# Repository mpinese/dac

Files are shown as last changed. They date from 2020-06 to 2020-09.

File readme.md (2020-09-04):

# Note

This project is still under active design, and is not yet completed! Do not build it expecting a functional device... yet.

# An (Almost) No Compromise USB Stereo DAC

This project describes the hardware and firmware for a high-quality DIY USB stereo digital to analogue converter (DAC) with optional integrated digital volume control and headphone amplifier.

## Background

I was after a DAC for my computer headphone setup. Seeing as I enjoy a bit of DIY hardware, I thought to have a go at designing the ideal DAC for me. This would be a high-quality but fairly compact single-box DAC, with integrated preamp and headphone amplifier. If stereo line out and digital (eg S/PDIF in) could be included with minimal effort that would be a bonus.

## Design philosophy

The design is balanced towards maximum audio quality while hopefully avoiding audiophile silliness. Close attention is paid to performance of the key components, gain structure, power rails, stability, and transfer characteristics in the 20-20kHz spectrum. However, you won't see esoteric components, valves, absurdly overspecified linear power supplies / space heaters, etc.

Key principles in the design were:
1. Use asynchronous mode USB audio. I want the PC to have as little influence as possible on the audio playback.
2. Keep the signal digital for as long as possible. For example, perform volume control digitally, rather than using an analogue attenuation stage, which can introduce issues with rolloff and noise.
3. Maintain a simple and clean analog signal path, ideally DC-coupled.
4. Have a solid justification for each design decision; try and avoid reflexive overkill approaches.
5. Where suitable, source components from the [JLCPCB SMT parts library](https://jlcpcb.com/parts/componentSearch). This is a practical and cost-saving measure that is well-worth it for non-critical things like pull-up resistors and decoupling caps.
6. Keep cost under control. Only use high-cost components if lower-cost alternatives are unsuitable.

I would have liked to add '0. Test everything, remove anything unnecessary' but unfortuantely I do not have the kind of test equipment needed to really challenge the design. Therefore some design choices, for example the supply decoupling or separate PSU enclosure, feel a bit over-the-top and can probably be optimised.

## Architecture

```
                                     Panel controls
                                           |
                                           v
                                     +--- MCU ---+
                                     |           |
                                     v           v
  Computer  -->  USB to I2S  -->  Receiver -->  DAC  -->  I2V  -->  Amplifier  -->  Headphones
                                  and ASRC                 |
                                     ^                     v
                                     |                  Line out
                                 Digital in            (3.472 Vpp)
```

* USB to I2S: [Amanero module](https://amanero.com/). A well-established solution for asynchronous USB to I2S conversion. I considered adopting a DIY approach for this stage, but there's no way I could replicate the Amanero's functionality without an investment of effort that far exceeds the cost of the module.
* Clock: Onboard 24.576 MHz oscillator driving both the ASRC and the DAC. The Amanero MCLK output is not used. Simulations indicated that the Kyocera ### is good enough here, and that the popular Crystek CHD series crystal, which has better specs but costs 10X more, is overkill.
* Receiver and ASRC: SRC4392, converting input to fs=96 kHz. This stage also performs digital volume control / attenuation if required.
* DAC: PCM1792A running at fs=96 kHz, with slow rolloff reconstruction filter.
* I2V: Op-amp based, standard Philips architecture of dual transimpedance amplifiers followed by a difference stage. OPA1612 devices for minimum noise. Gain flat within 0.1 dB 20 Hz to 20 kHz. Phase linear within 5 deg to 20 kHz (group delay < 0.1 ms). Total noise < 700 nV RMS (20 Hz - 20 kHz), equivalent to -125 dB relative to +4 dBu output level.
* Amplifier: OPA1612 + LME49600 buffer in feedback loop, unity gain (therefore maximum output level is 3.472 Vpp, matching the line out). AC-coupled input to avoid headphone damage in the case of DC signal, -3 dB at 7.7 Hz, -0.6 dB at 20 Hz, -0.1 dB at 50 Hz and higher; group delay 2.6 ms at 20 Hz, < 0.5 ms at 50 Hz and higher.  Somewhat overkill: characterised down to 16 ohm headphones, stable for all reasonable capacitances, and should be capable of driving any dynamic headphone or IEM out there.
* MCU: STM8S003F3P
* PSU: Switchmode modules for analog and digital supplies, in an external enclosure with LC filtering. In the main DAC enclosure, TPS7A linear postregulators for analog rails.

## Capabilities

* USB input: 
* Digital input: 
* Headphone output: 

## Options

The design is modular and modules can be left out to cut costs or change functionality.  The main modules are:

### Core DAC: essential

This is the only required module.  It performs USB --> stereo analog conversion.

#### Line out startup mute: optional

This module mutes the stereo output while the power rails are unstable (eg during startup).  It prevents the "thump" noise that can often happen when switching the DAC on or off.  However this may not be required in some configurations.

To disable this module, leave out components: 

### Volume control: optional (though highly recommended if headphones are used)

To disable this module, bridge ###

### Headphone amplifier: optional

Components: 

#### Headphone startup mute: optional

Components: 

## Licence

Hardware designs (schematics, PCB layouts, and enclosure plans), software, and documentation are licensed for reuse under the Creative Commons Attribution 4.0 Licence (CC BY 4.0). For more details on this licence, visit https://creativecommons.org/licenses/by/4.0/.

Component models (3D and 2D) under the design/pcbs/lib directory, and simulation models (`*.s*p`, `*.lib`, `*.tld`, `*.TSM` under the simulations directory) remain the property of their creators and are not covered by this CC BY 4.0 licence.

The Kicad BOM template bom2grouped_csv_jlcpcb.xsl was created bt arturo182, see https://gist.github.com/arturo182/a8c4a4b96907cfccf616a1edb59d0389.

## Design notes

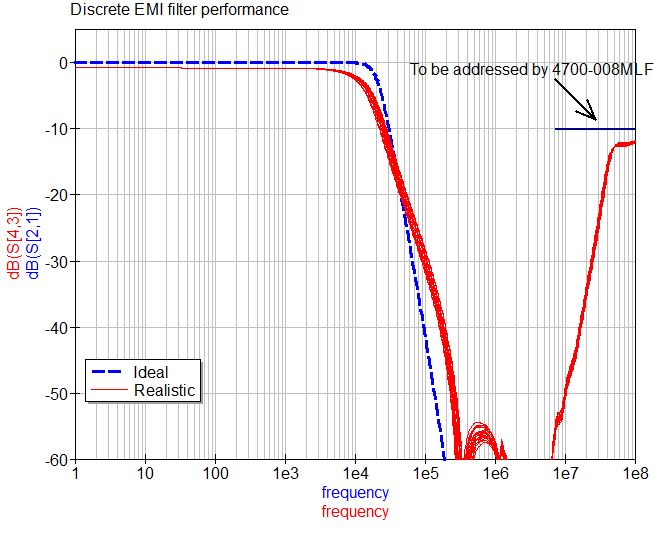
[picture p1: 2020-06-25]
simulations/qucsstudio/emi_filter.png

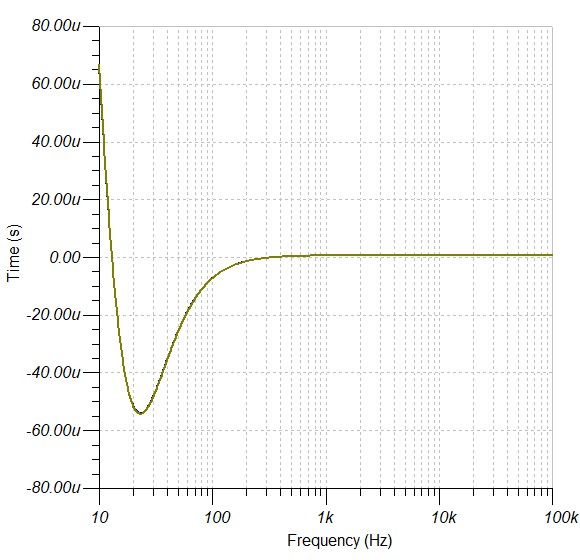
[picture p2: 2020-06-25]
simulations/tina-ti/i2v_delay.jpg

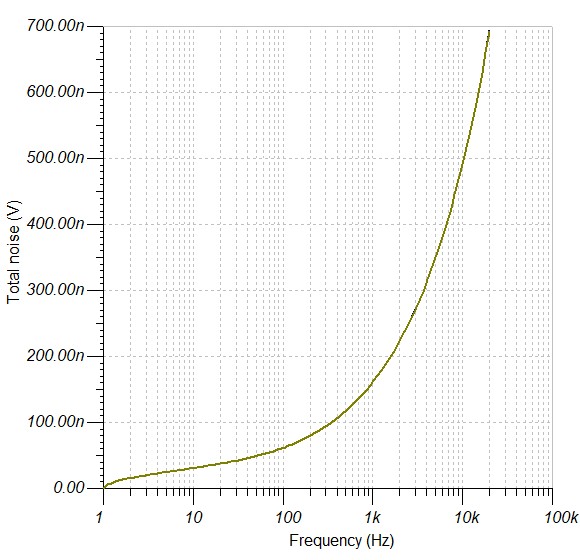
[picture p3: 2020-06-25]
simulations/tina-ti/i2v_noise.jpg

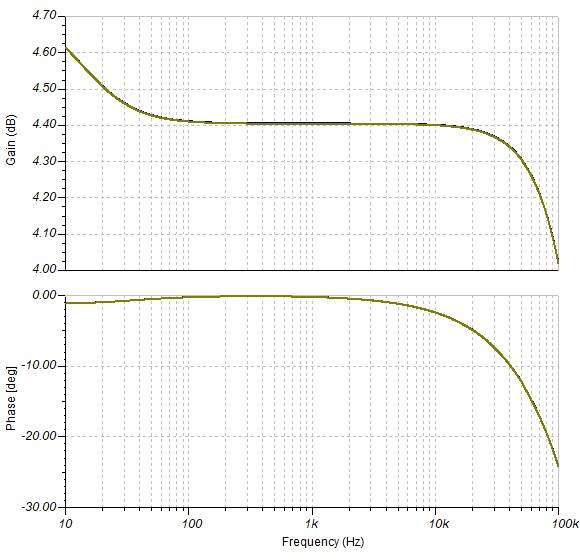
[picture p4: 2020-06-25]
simulations/tina-ti/I2V_ac.jpg

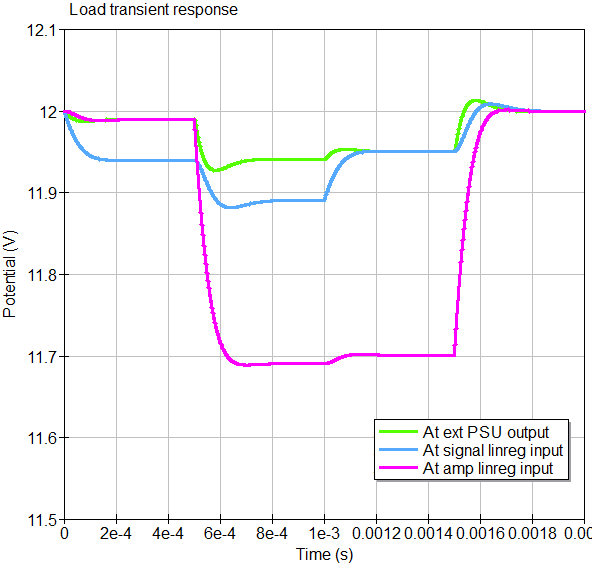
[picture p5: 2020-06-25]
simulations/qucsstudio/psu_transient.png

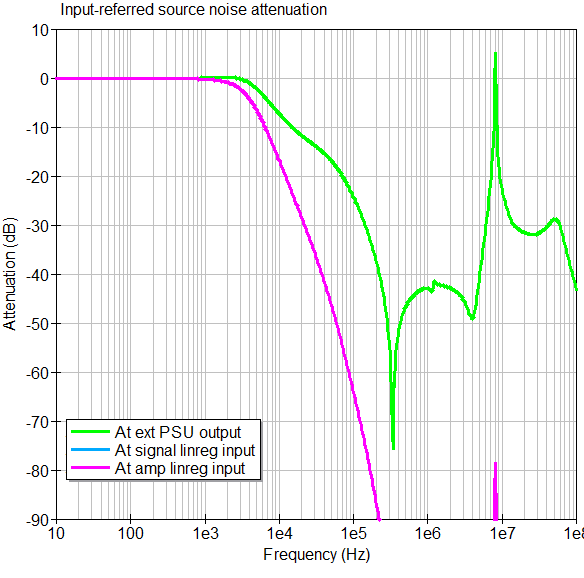
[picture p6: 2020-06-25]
simulations/qucsstudio/psu_ac.png

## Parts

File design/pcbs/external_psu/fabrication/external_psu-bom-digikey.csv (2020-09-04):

Comment | Designator | Footprint | DigiKey | Quantity
6.8u | C1,C13,C2,C14,C3,C15 | Capacitor_THT:CP_Radial_D5.0mm_P2.00mm | 565-4006-ND | 6
2.2u | C4,C10,C5,C11,C6,C12 | Capacitor_SMD:C_1206_3216Metric | 1276-3137-1-ND | 6
15n | C7,C8,C9 | Capacitor_SMD:C_0805_2012Metric_Pad1.15x1.40mm_HandSolder | 732-12189-1-ND | 3
~ | #FB1 |  | 240-2497-ND | 1
EMI_Filter_CLC | FL1,FL2,FL3 | dac:4700-008MLF | 410-1196-1-ND | 3
15u | L1,L2,L3 | dac:NRS5020T150MMGJ | 587-2410-1-ND | 3
RAC20-12DK | PS1 | CONV_RAC20-12DK | 945-3239-ND | 1
RAC03-05SK | PS2 | CONV_RAC03-05SK | 945-3441-ND | 1
IEC 320-C14 socket | #J1 |  | Q334-ND | 1
XLR5 | #J2 |  | 1937-1035-ND | 1

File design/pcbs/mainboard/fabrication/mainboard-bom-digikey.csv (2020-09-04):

Comment | Designator | Footprint | DigiKey | Quantity
KC3225K24.5760C1GE00 | U6 | Crystal:Crystal_SMD_3225-4Pin_3.2x2.5mm | 1253-1407-1-ND | 1
100u | C16 | Capacitor_THT:CP_Radial_D8.0mm_P3.50mm | 1572-1662-ND | 1
TPS79318-EP | U10 | Package_TO_SOT_SMD:SOT-23-5 | 296-12155-1-ND | 1
SRC4392 | U11 | Package_QFP:TQFP-48_7x7mm_P0.5mm | 296-19740-1-ND | 1
PCM1792A | U12 | Package_SO:SSOP-28_5.3x10.2mm_P0.65mm | 296-26303-5-ND | 1
TPS7A30 | U3,U16 | Package_SO:MSOP-8-1EP_3x3mm_P0.65mm_EP1.68x1.88mm_ThermalVias | 296-27750-1-ND | 2
TPS7A49 | U2,U19,U5 | Package_SO:MSOP-8-1EP_3x3mm_P0.65mm_EP1.68x1.88mm_ThermalVias | 296-27751-1-ND | 3
TLV1117-33 | U4 | Package_TO_SOT_SMD:SOT-223-3_TabPin2 | 296-28778-1-ND | 1
OPA1612AxD | U18,U15,U9,U13 | Package_SO:SOIC-8_3.9x4.9mm_P1.27mm | 296-39098-1-ND | 4
LME49600 | U17,U20 | Package_TO_SOT_SMD:TO-263-5_TabPin3 | 296-43968-5-ND | 2
Si8645BA-B-IU | U14 | Package_SO:QSOP-16_3.9x4.9mm_P0.635mm | 336-2096-5-ND | 1
EC2-12NU | K3,K4 | RELAY_EC2-5NU | 399-11029-5-ND | 2
EC2-5NU | K1,K2 | mainboard:RELAY_EC2-5NU | 399-11052-5-ND | 2
1.2n | C37,C38,C65,C66 | Capacitor_SMD:C_0603_1608Metric | 399-14950-1-ND | 4
430p | C47,C24,C69,C53 | Capacitor_SMD:C_0603_1608Metric | 399-15401-1-ND | 4
4.7 | R49 | Resistor_SMD:R_0603_1608Metric | 408-1436-1-ND | 1
2.2u | C80,C79,C94,C95 | Capacitor_THT:C_Rect_L18.0mm_W11.0mm_P15.00mm_FKS3_FKP3 | 732-11840-ND | 4
47u | C15,C12,C4,C5,C93,C78,C86,C77,C6 | Capacitor_THT:CP_Radial_D8.0mm_P3.50mm | 732-6324-1-ND | 9
47u | C42,C59,C29 | Capacitor_THT:CP_Radial_D5.0mm_P2.00mm | 732-9306-1-ND | 3
25 | R38,R42 | Resistor_SMD:R_0603_1608Metric | 764-1409-1-ND | 2
5PB1102 | U8 | Package_SO:TSSOP-8_4.4x3mm_P0.65mm | 800-2889-5-ND | 1
AudioJackSw | J10 | mainboard:Amphenol_ACJS-MHOM | 889-1818-ND | 1
P091S-FC20BR10K | RV1 | mainboard:P091S-FC20BR10K | 987-1283-ND | 1
1k | R30,R28,R50,R48 | Resistor_SMD:R_0603_1608Metric | RG16N1.0KWCT-ND | 4
270 | R33,R34,R46,R47 | Resistor_SMD:R_0603_1608Metric | RG16N270WCT-ND | 4
820 | R35,R27,R53,R43 | Resistor_SMD:R_0603_1608Metric | RG16N820WCT-ND | 4
4.7k | R60,R70 | Resistor_SMD:R_0603_1608Metric | RG16P4.7KBCT-ND | 2
Conn_Coaxial | J7,J8 | Connector_Wire:SolderWirePad_1x02_P5.08mm_Drill1.5mm | SC1828-ND | 2
XLR5 | #J3 |  | IO-XLR5-M-EV | 1

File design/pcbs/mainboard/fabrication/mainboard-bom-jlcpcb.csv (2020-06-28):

Comment | Designator | Footprint | LCSC
10n | C18,C17,C9,C11,C72,C87,C85,C71,C28,C19,C21,C34,C22,C35 | Capacitor_SMD:C_0603_1608Metric | C14663
0.1u | C44,C61,C54,C51,C33,C60,C45,C84,C88,C81,C96,C75,C92,C32,C63,C48,C68,C58,C26,C41,C46,C57,C3,C2 | Capacitor_SMD:C_0603_1608Metric | C14663
10n | C39 | Capacitor_SMD:C_0402_1005Metric | C15195
1 | R2,R3,R4,R62,R56 | Resistor_SMD:R_1206_3216Metric | C17928
75 | R16 | Resistor_SMD:R_1206_3216Metric | C17985
SS8050 | Q12,Q11,Q9,Q8,Q1,Q2,Q4,Q5,Q6,Q7 | Package_TO_SOT_SMD:SOT-23 | C2150
2.2u | C55 | Capacitor_SMD:C_0603_1608Metric | C23630
100 | R8,R7 | Resistor_SMD:R_0402_1005Metric | C25076
50 | R39,R41,R44 | Resistor_SMD:R_0402_1005Metric | C25082
10k | R32,R37,R1,R5,R71,R21 | Resistor_SMD:R_0402_1005Metric | C25744
120k | R23,R22,R55,R65 | Resistor_SMD:R_0402_1005Metric | C25750
15k | R73,R20 | Resistor_SMD:R_0402_1005Metric | C25756
220k | R26 | Resistor_SMD:R_0402_1005Metric | C25767
22k | R63,R31 | Resistor_SMD:R_0402_1005Metric | C25768
27k | R24,R10,R58,R67 | Resistor_SMD:R_0402_1005Metric | C25771
330k | R18,R17,R54,R64 | Resistor_SMD:R_0402_1005Metric | C25778
33k | R19,R15,R57,R66 | Resistor_SMD:R_0402_1005Metric | C25779
2.2k | R74,R72,R11,R13 | Resistor_SMD:R_0402_1005Metric | C25879
2.4k | R9,R6 | Resistor_SMD:R_0402_1005Metric | C25882
5.6k | R69,R68,R12,R14 | Resistor_SMD:R_0402_1005Metric | C25908
1u | C7,C10,C8,C73,C89,C20,C1 | Capacitor_SMD:C_0805_2012Metric | C28323
68k | R25 | Resistor_SMD:R_0402_1005Metric | C36871
22u | C40,C82 | Capacitor_SMD:C_0805_2012Metric | C45783
2.2u | C14,C13,C76,C90,C27 | Capacitor_SMD:C_1206_3216Metric | C50254
STM8S003F3P | U1 | Package_SO:TSSOP-20_4.4x6.5mm_P0.65mm | C52717
M7 | D1 | Diode_SMD:D_SOD-123F | C64898
D | D5,D4 | Diode_SMD:D_SOD-123F | C64898
10u | C43,C30,C64,C83,C97,C74,C91,C67,C56,C49,C31,C25,C52,C70,C23,C50,C36,C62 | Capacitor_Tantalum_SMD:CP_EIA-3216-18_Kemet-A | C7171
5V6 | D7,D6,D2,D3 | Diode_SMD:D_MiniMELF | C8062
SS8550 | Q10,Q3 | Package_TO_SOT_SMD:SOT-23 | C8542

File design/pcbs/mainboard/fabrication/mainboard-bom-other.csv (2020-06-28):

Comment | Designator | Footprint
Optional | FB1,FB2 | Resistor_SMD:R_0603_1608Metric_Pad1.05x0.95mm_HandSolder
MountingHole | H2,H4,H1,H5,H3 | MountingHole:MountingHole_3.2mm_M3_Pad_Via
Conn_01x01 | J2,J1,J3,J4 | Connector_Wire:SolderWirePad_1x01_Drill1.5mm
Conn_01x04 | J6,J5 | Connector_PinHeader_2.54mm:PinHeader_1x04_P2.54mm_Vertical
Conn_01x03 | J9 | Connector_PinHeader_2.54mm:PinHeader_1x03_P2.54mm_Vertical
Jumper_NC_Small | JP1 | Jumper:SolderJumper-2_P1.3mm_Bridged2Bar_Pad1.0x1.5mm
Jumper | JP10 | Jumper:SolderJumper-2_P1.3mm_Bridged2Bar_Pad1.0x1.5mm
Jumper | JP2,JP3 | Connector_PinHeader_2.54mm:PinHeader_1x02_P2.54mm_Vertical
~ | JP4,JP5,JP9,JP8,JP7,JP6 | Connector_PinHeader_2.54mm:PinHeader_1x02_P2.54mm_Vertical
Optional | R29,R36,R52,R51,R45,R40 | Resistor_THT:R_Axial_DIN0204_L3.6mm_D1.6mm_P5.08mm_Horizontal
Open | R59,R76 | Resistor_THT:R_Axial_DIN0207_L6.3mm_D2.5mm_P10.16mm_Horizontal
0 | R61,R75 | Resistor_THT:R_Axial_DIN0207_L6.3mm_D2.5mm_P10.16mm_Horizontal
TestPoint | TP2,TP3,TP1,TP6,TP7,TP9,TP8,TP5,TP4 | TestPoint:TestPoint_THTPad_D3.0mm_Drill1.5mm
Combo384 | U7 | mainboard:AmaneroCombo384

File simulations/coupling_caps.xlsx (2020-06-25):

Digi-Key Part Number | Quantity Available | Series | Capacitance | n | Cost | Package / Case | Totlength | Totwidth | Totarea
P16728-ND | 1262 | ECW-F(D) | 4.7 | 1 | 1.31 | Radial | 25.3 | 10.7 | 270.71
P19146-ND | 440 | ECWFE | 4.7 | 1 | 1.32 | Radial | 26 | 12 | 312
P16718-ND | 9 | ECW-F(D) | 2.7 | 2 | 1.8 | Radial | 50.6 | 18 | 910.8
P16722-ND | 2669 | ECW-F(D) | 3.3 | 2 | 2.08 | Radial | 50.6 | 19.6 | 991.76
P16847-ND | 22 | ECWFE | 2.2 | 2 | 2.12 | Radial | 35 | 20 | 700
PCF1610-ND | 893 | ECW-F(D) | 2.2 | 2 | 2.12 | Radial | 35 | 22.2 | 777
PCF1594CT-ND | 406 | ECW-F(D) | 2.2 | 2 | 2.16 | Radial | 35 | 22.2 | 777
P16717-ND | 3197 | ECW-F(D) | 2.7 | 2 | 2.18 | Radial | 50.6 | 18 | 910.8
PCF1595CT-ND | 165 | ECW-F(D) | 2.2 | 2 | 2.22 | Radial | 35 | 22.2 | 777
P122599-ND | 461 | ECW-F(D) | 4.7 | 1 | 2.27 | Radial | 25.3 | 18.3 | 462.99
P122575-ND | 78 | ECW-F(D) | 4.7 | 1 | 2.38 | Radial | 25.3 | 18.3 | 462.99
P14214-ND | 1102 | ECW-F(A) | 4.7 | 1 | 3.12 | Radial | 26.3 | 13.8 | 362.94
732-11840-ND | 897 | WCAP-FTBP | 2.2 | 2 | 3.76 | Radial | 36 | 20 | 720
P13748-ND | 1275 | ECW-F(A) | 2.2 | 2 | 3.84 | Radial | 37.6 | 25.2 | 947.52
P13754-ND | 2533 | ECW-F(A) | 5.6 | 1 | 4.34 | Radial | 23.8 | 16.2 | 385.56
1572-1504-ND | 109 | PHC | 5 | 1 | 4.46 | Axial | 18.5 | 34 | 629
338-4496-ND | 94 | 936C | 4.7 | 1 | 5.1 | Axial | 22.35 | 16.26 | 363.411
495-4717-ND | 8855 | B32672P | 2.2 | 2 | 5.14 | Radial | 36 | 22 | 792
493-10191-ND | 62 | QAP | 4.7 | 1 | 5.67 | Axial | 23.8 | 14.1 | 335.58
493-10201-ND | 98 | QAP | 4.7 | 1 | 6.36 | Axial | 28.7 | 19 | 545.3
732-11847-ND | 223 | WCAP-FTBP | 3.3 | 2 | 7.26 | Radial | 52 | 18 | 936
493-10189-ND | 52 | QAP | 2.2 | 2 | 7.82 | Axial | 38 | 21.6 | 820.8
338-4200-ND | 2 | 935C | 5 | 1 | 10.2 | Axial | 19.5 | 44.4 | 865.8
338-3161-ND | 11 | 935C | 5 | 1 | 12.69 | Axial | 16.3 | 31.7 | 516.71
1572-1470-ND | 713 | PHC | 4.7 | 1 | 4.75 | Axial | 22 | 46 | 1012
338-4497-ND | 446 | 950 | 5 | 1 | 4.45 | Axial | 23 | 44.5 | 1023.5
1572-1505-ND | 56 | PHC | 5 | 1 | 6.54 | Axial | 22.5 | 46 | 1035
P19150-ND | 228 | ECWFE | 3.3 | 2 | 2.04 | Radial | 52 | 20 | 1040
P19151-ND | 161 | ECWFE | 3.3 | 2 | 2.08 | Radial | 52 | 20 | 1040
P16725-ND | 1225 | ECW-F(D) | 3.9 | 2 | 2.96 | Radial | 50.6 | 21.4 | 1082.84
P13749-ND | 267 | ECW-F(A) | 2.7 | 2 | 4.4 | Radial | 47.6 | 22.8 | 1085.28
495-75592-ND | 14497 | B32673P | 2.2 | 2 | 4.04 | Radial | 53 | 21 | 1113
P14211-ND | 631 | ECW-F(A) | 2.7 | 2 | 4.68 | Radial | 52.6 | 21.2 | 1115.12
399-F426DT225J250C-ND | 506 | PHE426 | 2.2 | 2 | 5.6 | Radial | 52 | 22 | 1144
399-18293-ND | 625 | R75 | 2.2 | 2 | 3.56 | Radial | 53 | 22 | 1166
399-12739-ND | 3067 | R71 | 2.2 | 2 | 3.6 | Radial | 53 | 22 | 1166
1928-1595-ND | 493 | - | 2.2 | 2 | 3.68 | Radial | 53 | 22 | 1166
1928-1544-ND | 732 | - | 2.2 | 2 | 3.74 | Radial | 53 | 22 | 1166
1928-1545-ND | 2 | - | 2.2 | 2 | 3.78 | Radial | 53 | 22 | 1166
493-10190-ND | 107 | QAP | 3.3 | 2 | 9.22 | Axial | 45.2 | 25.8 | 1166.16
P13750-ND | 627 | ECW-F(A) | 3.3 | 2 | 4.4 | Radial | 47.6 | 25 | 1190
P14212-ND | 2991 | ECW-F(A) | 3.3 | 2 | 5.3 | Radial | 52.6 | 23.4 | 1230.84
495-76555-ND | 2984 | B32673P | 2.2 | 2 | 4.36 | Radial | 53 | 24 | 1272
P13751-ND | 1209 | ECW-F(A) | 3.9 | 2 | 6.84 | Radial | 47.6 | 27 | 1285.2
P14213-ND | 961 | ECW-F(A) | 3.9 | 2 | 6.26 | Radial | 52.6 | 25.2 | 1325.52
399-17027-ND | 3656 | F861 | 2.2 | 2 | 3.86 | Radial | 52 | 26 | 1352
399-5890-ND | 2028 | R46 | 2.2 | 2 | 3.16 | Radial | 53 | 26 | 1378
399-12528-ND | 485 | R71 | 2.2 | 2 | 3.78 | Radial | 53 | 26 | 1378
399-12560-ND | 127 | R75 | 3.3 | 2 | 4.56 | Radial | 53 | 26 | 1378
493-10199-ND | 294 | QAP | 2.2 | 2 | 9.34 | Axial | 48.4 | 29.6 | 1432.64
495-4739-ND | 5501 | B32672P | 1.5 | 3 | 6.24 | Radial | 54 | 27 | 1458
495-4741-ND | 3073 | B32672P | 1.8 | 3 | 6.54 | Radial | 54 | 27 | 1458
495-4740-ND | 2718 | B32672P | 2 | 3 | 6.93 | Radial | 54 | 27 | 1458
PCF1612-ND | 211 | ECW-F(D) | 1.5 | 3 | 2.4 | Radial | 52.5 | 27.9 | 1464.75
PCF1613-ND | 3440 | ECW-F(D) | 1.5 | 3 | 2.82 | Radial | 52.5 | 27.9 | 1464.75
495-1885-ND | 153549 | B32923 | 2.2 | 2 | 3 | Radial | 53 | 29 | 1537
495-7043-ND | 2517 | B32923 | 2.2 | 2 | 6.74 | Radial | 53 | 29 | 1537
338-3951-ND | 5 | 935C | 5 | 1 | 17.43 | Axial | 27.1 | 57.1 | 1547.41
P122573-ND | 294 | ECW-F(D) | 3.3 | 2 | 3.62 | Radial | 50.6 | 30.6 | 1548.36
P122597-ND | 408 | ECW-F(D) | 3.3 | 2 | 3.82 | Radial | 50.6 | 30.6 | 1548.36
732-5864-ND | 114 | WCAP-FTXX | 2.2 | 2 | 6.12 | Radial | 52 | 30 | 1560
732-5764-ND | 42 | WCAP-FTXX | 2.2 | 2 | 6.12 | Radial | 52 | 30 | 1560
732-5914-ND | 184 | WCAP-FTX2 | 2.2 | 2 | 6.24 | Radial | 52 | 30 | 1560
732-5814-ND | 100 | WCAP-FTX2 | 2.2 | 2 | 6.24 | Radial | 52 | 30 | 1560
P19157-ND | 782 | ECWFE | 1.5 | 3 | 2.4 | Radial | 52.5 | 30 | 1575
P19156-ND | 626 | ECWFE | 1.5 | 3 | 2.61 | Radial | 52.5 | 30 | 1575
PCF1608-ND | 372 | ECW-F(D) | 1.8 | 3 | 2.64 | Radial | 52.5 | 30.3 | 1590.75
399-17028-ND | 3565 | F861 | 2.7 | 2 | 4.72 | Radial | 52 | 31 | 1612
399-17029-ND | 136 | F861 | 3.3 | 2 | 4.86 | Radial | 52 | 31 | 1612
BC3111-ND | 93 | MKP1839 | 2.2 | 2 | 5.74 | Axial | 26 | 63 | 1638
732-11844-ND | 382 | WCAP-FTBP | 1.5 | 3 | 6.09 | Radial | 78 | 21 | 1638
493-10188-ND | 157 | QAP | 1.5 | 3 | 9.66 | Axial | 54.6 | 30.3 | 1654.38
P19145-ND | 5100 | ECWFE | 2.2 | 2 | 3.12 | Radial | 52 | 32 | 1664
P19144-ND | 2694 | ECWFE | 2.2 | 2 | 3.88 | Radial | 52 | 32 | 1664
P124088-ND | 386 | ECWFG | 2.2 | 2 | 3.26 | Radial | 54 | 31 | 1674
P124096-ND | 500 | ECWFG | 2.2 | 2 | 3.44 | Radial | 54 | 31 | 1674
P124084-ND | 368 | ECWFG | 2.2 | 2 | 3.64 | Radial | 54 | 31 | 1674
P124092-ND | 459 | ECWFG | 2.2 | 2 | 3.8 | Radial | 54 | 31 | 1674
P122598-ND | 777 | ECW-F(D) | 3.9 | 2 | 3.96 | Radial | 50.6 | 33.2 | 1679.92
P122574-ND | 301 | ECW-F(D) | 3.9 | 2 | 4.16 | Radial | 50.6 | 33.2 | 1679.92
338-1142-ND | 687 | 940C | 4.7 | 1 | 12.79 | Axial | 31.5 | 54 | 1701
399-11778-ND | 501 | C4G | 5 | 1 | 6.78 | Axial | 30.5 | 58 | 1769
P13746-ND | 439 | ECW-F(A) | 1.5 | 3 | 4.86 | Radial | 56.4 | 31.5 | 1776.6
493-10209-ND | 175 | QAP | 2.2 | 2 | 12.12 | Axial | 53 | 33.6 | 1780.8
399-12511-ND | 1745 | R71 | 1.5 | 3 | 3.78 | Radial | 54 | 33 | 1782
495-4727-ND | 94 | B32672P | 1.5 | 3 | 4.2 | Radial | 54 | 33 | 1782
493-10200-ND | 88 | QAP | 3.3 | 2 | 11.24 | Axial | 53.2 | 33.8 | 1798.16
P14208-ND | 55127 | ECW-F(A) | 1.5 | 3 | 5.16 | Radial | 56.4 | 32.1 | 1810.44
P12240-ND | 991 | ECW-F(L) | 2.2 | 2 | 5.42 | Radial | 56 | 33.6 | 1881.6
P12215-ND | 596 | ECW-F(L) | 2.2 | 2 | 6.32 | Radial | 56 | 33.6 | 1881.6
P124089-ND | 272 | ECWFG | 3 | 2 | 3.6 | Radial | 54 | 35 | 1890
P124093-ND | 294 | ECWFG | 3 | 2 | 4.22 | Radial | 54 | 35 | 1890
P13747-ND | 940 | ECW-F(A) | 1.8 | 3 | 5.7 | Radial | 56.4 | 34.2 | 1928.88
P12241-ND | 982 | ECW-F(L) | 2.4 | 2 | 5.64 | Radial | 56 | 35 | 1960
P12216-ND | 995 | ECW-F(L) | 2.4 | 2 | 6.56 | Radial | 56 | 35 | 1960
P14209-ND | 12933 | ECW-F(A) | 1.8 | 3 | 5.43 | Radial | 56.4 | 34.8 | 1962.72
1572-1119-ND | 1142 | PHC | 3 | 2 | 8.34 | Axial | 30 | 68 | 2040
493-10210-ND | 81 | QAP | 3.3 | 2 | 14.06 | Axial | 58.2 | 38.8 | 2258.16
399-13090-ND | 578 | C4G | 2.2 | 2 | 8.14 | Axial | 35 | 66 | 2310
1572-1338-ND | 2643 | MKP | 1.5 | 3 | 4.68 | Radial | 78 | 30 | 2340
732-5763-ND | 337 | WCAP-FTXX | 1.5 | 3 | 7.53 | Radial | 78 | 30 | 2340
732-5813-ND | 49 | WCAP-FTX2 | 1.5 | 3 | 7.92 | Radial | 78 | 30 | 2340
732-5913-ND | 23 | WCAP-FTX2 | 1.5 | 3 | 7.92 | Radial | 78 | 30 | 2340
P122593-ND | 644 | ECW-F(D) | 1.5 | 3 | 3.21 | Radial | 75.9 | 30.9 | 2345.31
P122569-ND | 675 | ECW-F(D) | 1.5 | 3 | 3.36 | Radial | 75.9 | 30.9 | 2345.31
399-18292-ND | 247 | R75 | 1.5 | 3 | 4.41 | Radial | 79.5 | 30 | 2385
1928-1543-ND | 470 | - | 1.5 | 3 | 4.83 | Radial | 79.5 | 31.5 | 2504.25
P122594-ND | 814 | ECW-F(D) | 1.8 | 3 | 3.69 | Radial | 75.9 | 33.6 | 2550.24
P122570-ND | 763 | ECW-F(D) | 1.8 | 3 | 3.9 | Radial | 75.9 | 33.6 | 2550.24
1572-1377-ND | 142 | MPW | 2.2 | 2 | 5.26 | Axial | 38 | 68 | 2584
399-12527-ND | 47 | R71 | 1.5 | 3 | 3.93 | Radial | 79.5 | 33 | 2623.5
399-12707-ND | 250 | R46 | 1.5 | 3 | 4.92 | Radial | 79.5 | 33 | 2623.5
399-12559-ND | 57 | R75 | 1.8 | 3 | 5.01 | Radial | 79.5 | 33 | 2623.5
493-10198-ND | 1963 | QAP | 1.5 | 3 | 13.11 | Axial | 69.3 | 40.2 | 2785.86
P19149-ND | 132 | ECWFE | 1.5 | 3 | 3.45 | Radial | 78 | 36 | 2808
P19148-ND | 454 | ECWFE | 1.5 | 3 | 3.84 | Radial | 78 | 36 | 2808
493-14297-ND | 213 | QXP | 1.5 | 3 | 10.02 | Radial | 79.5 | 35.4 | 2814.3
493-10208-ND | 18 | QAP | 1.5 | 3 | 13.83 | Axial | 69.6 | 40.5 | 2818.8
1572-1120-ND | 3156 | PHC | 3 | 2 | 9.46 | Axial | 42 | 68 | 2856
P13745-ND | 2051 | ECW-F(A) | 1.2 | 4 | 5.36 | Radial | 75.2 | 38 | 2857.6
495-4938-1-ND | 20047 | B32923 | 1.5 | 3 | 3.63 | Radial | 79.5 | 36 | 2862
BC2615-ND | 325 | MKP1839 HQ | 2.2 | 2 | 15.06 | Axial | 46 | 63 | 2898
338-3948-ND | 140 | 935C | 2 | 3 | 34.14 | Axial | 40.8 | 71.4 | 2913.12
P124087-ND | 600 | ECWFG | 1.5 | 3 | 3.63 | Radial | 81 | 36 | 2916
P124095-ND | 590 | ECWFG | 1.5 | 3 | 3.81 | Radial | 81 | 36 | 2916
P124083-ND | 600 | ECWFG | 1.5 | 3 | 4.02 | Radial | 81 | 36 | 2916
P124091-ND | 600 | ECWFG | 1.5 | 3 | 4.2 | Radial | 81 | 36 | 2916
P14207-ND | 1663 | ECW-F(A) | 1.2 | 4 | 5.68 | Radial | 75.2 | 38.8 | 2917.76
P16846-ND | 1694 | ECWFE | 1 | 5 | 3.3 | Radial | 87.5 | 35 | 3062.5
P16845-ND | 989 | ECWFE | 1 | 5 | 3.8 | Radial | 87.5 | 35 | 3062.5
399-18733-ND | 505 | R46 | 1.5 | 3 | 3.09 | Radial | 79.5 | 39 | 3100.5
399-14810-ND | 2310 | F863 | 1.5 | 3 | 4.44 | Radial | 79.5 | 39 | 3100.5
399-14832-ND | 1408 | F863 | 1.5 | 3 | 4.47 | Radial | 79.5 | 39 | 3100.5
399-14824-1-ND | 85 | F863 | 1.5 | 3 | 5.28 | Radial | 79.5 | 39 | 3100.5
399-18301-ND | 180 | R75 | 1.5 | 3 | 5.7 | Radial | 79.5 | 39 | 3100.5
732-11832-ND | 559 | WCAP-FTBP | 1 | 5 | 4.95 | Radial | 90 | 35 | 3150
PCF1568-ND | 261 | ECW-F(A) | 1.5 | 3 | 3.84 | Radial | 78 | 40.5 | 3159
338-4372-ND | 27 | 930C | 3 | 2 | 12.78 | Axial | 35.6 | 88.8 | 3161.28
493-10187-ND | 191 | QAP | 1 | 5 | 15.65 | Axial | 81 | 40 | 3240
1572-1804-ND | 1621 | MPX | 1.5 | 3 | 3.84 | Radial | 78 | 42 | 3276
PCF1616-ND | 989 | ECW-F(D) | 1 | 5 | 3.45 | Radial | 87.5 | 39 | 3412.5
PCF1615-ND | 415 | ECW-F(D) | 1 | 5 | 3.65 | Radial | 87.5 | 39 | 3412.5
PCF1596CT-ND | 93 | ECW-F(D) | 1 | 5 | 4.15 | Radial | 87.5 | 39 | 3412.5
P12236-ND | 508 | ECW-F(L) | 1.5 | 3 | 6.9 | Radial | 84 | 41.1 | 3452.4
P12211-ND | 1492 | ECW-F(L) | 1.5 | 3 | 8.13 | Radial | 84 | 41.1 | 3452.4
PCF1567-ND | 506 | ECW-F(A) | 1.8 | 3 | 4.41 | Radial | 78 | 44.4 | 3463.2
BC3112-ND | 448 | MKP1839 | 2.2 | 2 | 12.84 | Axial | 42 | 83 | 3486
BC2616-ND | 112 | MKP1839 HQ | 3.3 | 2 | 20.46 | Axial | 56 | 63 | 3528
P12237-ND | 218 | ECW-F(L) | 1.6 | 3 | 7.17 | Radial | 84 | 42.6 | 3578.4
P12212-ND | 1107 | ECW-F(L) | 1.6 | 3 | 8.46 | Radial | 84 | 42.6 | 3578.4
P122592-ND | 556 | ECW-F(D) | 1.2 | 4 | 4.08 | Radial | 101.2 | 36.8 | 3724.16
P122568-ND | 479 | ECW-F(D) | 1.2 | 4 | 4.28 | Radial | 101.2 | 36.8 | 3724.16
P12238-ND | 938 | ECW-F(L) | 1.8 | 3 | 7.47 | Radial | 84 | 45.6 | 3830.4
P12213-ND | 841 | ECW-F(L) | 1.8 | 3 | 8.79 | Radial | 84 | 45.6 | 3830.4
P13744-ND | 7764 | ECW-F(A) | 1 | 5 | 5.2 | Radial | 90.5 | 42.5 | 3846.25
P12239-ND | 212 | ECW-F(L) | 2 | 3 | 7.8 | Radial | 84 | 48 | 4032
P12214-ND | 1171 | ECW-F(L) | 2 | 3 | 9.15 | Radial | 84 | 48 | 4032
495-4734-ND | 8072 | B32672P | 1 | 5 | 6.55 | Radial | 90 | 45 | 4050
P14206-ND | 115939 | ECW-F(A) | 1 | 5 | 5.4 | Radial | 90.5 | 46.5 | 4208.25
1189-1822-ND | 6935 | MPK | 1 | 5 | 5.65 | Radial | 90 | 47.5 | 4275
399-5960-ND | 28891 | PHE426 | 1 | 5 | 8.4 | Radial | 90 | 47.5 | 4275
338-3950-ND | 50 | 935C | 3 | 2 | 34.86 | Axial | 48.8 | 88.8 | 4333.44
BC2076-ND | 387 | MKP416 | 1 | 5 | 23.65 | Radial | 87.5 | 50 | 4375
338-3162-ND | 382 | 935C | 2 | 3 | 32.91 | Axial | 46.2 | 95.1 | 4393.62
399-13454-ND | 750 | R71 | 1 | 5 | 5.05 | Radial | 90 | 50 | 4500
399-12510-ND | 697 | R71 | 1 | 5 | 5.05 | Radial | 90 | 50 | 4500
399-13455-ND | 393 | R75 | 1 | 5 | 5.55 | Radial | 90 | 50 | 4500
399-19307-ND | 155 | R75 | 1 | 5 | 5.95 | Radial | 90 | 50 | 4500
399-5961-ND | 292 | PHE426 | 1 | 5 | 7.35 | Radial | 130 | 35 | 4550
399-75IN4100AA40K-ND | 700 | R75 | 1 | 5 | 5.35 | Radial | 132.5 | 35 | 4637.5
399-18291-ND | 2535 | R75 | 1 | 5 | 5.7 | Radial | 132.5 | 35 | 4637.5
399-20906-ND | 498 | R75 | 1 | 5 | 6.15 | Radial | 132.5 | 35 | 4637.5
PF4155-ND | 86 | ECW-F(B) | 1.5 | 3 | 7.62 | Radial | 84 | 55.5 | 4662
399-12525-ND | 1248 | R71 | 1 | 5 | 5.5 | Radial | 90 | 55 | 4950
495-7067-ND | 2863 | B32672Z | 1 | 5 | 5.75 | Radial | 90 | 55 | 4950
495-6900-1-ND | 1428 | B32672Z | 1 | 5 | 6.95 | Radial | 90 | 55 | 4950
1572-1131-ND | 305 | PHC | 4 | 2 | 14.52 | Axial | 54 | 92 | 4968
P12233-ND | 979 | ECW-F(L) | 1.1 | 4 | 8.4 | Radial | 92 | 54.4 | 5004.8
PCF1569-ND | 120 | ECW-F(A) | 1.2 | 4 | 4.32 | Radial | 104 | 48.4 | 5033.6
399-13092-ND | 193 | C4G | 2.2 | 2 | 13.3 | Axial | 59 | 88 | 5192
P122591-ND | 1575 | ECW-F(D) | 1 | 5 | 4.5 | Radial | 126.5 | 42 | 5313
P122567-ND | 882 | ECW-F(D) | 1 | 5 | 4.8 | Radial | 126.5 | 42 | 5313
1572-1352-ND | 188 | PHC | 2 | 3 | 10.35 | Axial | 52.5 | 102 | 5355
399-11706-ND | 5084 | F862 | 1.2 | 4 | 7.12 | Radial | 104 | 52 | 5408
P12234-ND | 934 | ECW-F(L) | 1.2 | 4 | 8.64 | Radial | 112 | 49.2 | 5510.4
732-11845-ND | 378 | WCAP-FTBP | 1 | 5 | 10.15 | Radial | 130 | 42.5 | 5525
399-6794-ND | 11954 | R46 | 1 | 5 | 5.05 | Radial | 132.5 | 42.5 | 5631.25
399-11837-ND | 9 | R46 | 1 | 5 | 5.05 | Radial | 132.5 | 42.5 | 5631.25
338-3163-ND | 259 | 935C | 1 | 5 | 54.1 | Axial | 59.5 | 95 | 5652.5
P12235-ND | 64 | ECW-F(L) | 1.3 | 4 | 8.96 | Radial | 112 | 51.2 | 5734.4
338-1141-ND | 62 | 940C | 3.3 | 2 | 21.2 | Axial | 54 | 108 | 5832
1572-1018-ND | 2168 | MKP | 1 | 5 | 6.05 | Radial | 130 | 45 | 5850
399-12750-ND | 1246 | R75 | 1 | 5 | 7.4 | Radial | 90 | 65 | 5850
338-1149-ND | 331 | 940C | 2.2 | 2 | 29.74 | Axial | 64 | 92 | 5888
1572-1073-ND | 487 | PHC | 1.5 | 3 | 13.95 | Axial | 60 | 102 | 6120
338-1150-ND | 61 | 940C | 2.5 | 2 | 32.98 | Axial | 68 | 92 | 6256
493-10207-ND | 949 | QAP | 1 | 5 | 22.2 | Axial | 108 | 59.5 | 6426
493-14706-ND | 209 | QAP | 1 | 5 | 27.75 | Axial | 108 | 59.5 | 6426
P19153-ND | 53 | ECWFE | 1 | 5 | 4.9 | Radial | 130 | 50 | 6500
P19152-ND | 380 | ECWFE | 1 | 5 | 5.4 | Radial | 130 | 50 | 6500
BC2592-ND | 2108 | MKP339 | 1 | 5 | 9.55 | Radial | 130 | 50 | 6500
BC1602-ND | 297 | MKP338 2 | 1 | 5 | 17.5 | Radial | 130 | 50 | 6500
BC5075CT-ND | 665 | MKP339 | 1 | 5 | 18.05 | Radial | 130 | 50 | 6500
BC5069-ND | 292 | MKP339 | 1 | 5 | 21.8 | Radial | 130 | 50 | 6500
493-3637-ND | 1802 | QXP | 1 | 5 | 11.25 | Radial | 132.5 | 49.5 | 6558.75
493-14707-ND | 137 | QXP | 1 | 5 | 14.05 | Radial | 132.5 | 49.5 | 6558.75
399-11743-ND | 8392 | R46 | 1 | 5 | 4.35 | Radial | 132.5 | 50 | 6625
399-19294-ND | 339 | R46 | 1 | 5 | 4.5 | Radial | 132.5 | 50 | 6625
399-12694-ND | 1211 | R46 | 1 | 5 | 4.6 | Radial | 132.5 | 50 | 6625
399-19286-ND | 281 | R46 | 1 | 5 | 4.75 | Radial | 132.5 | 50 | 6625
399-5466-ND | 25918 | R46 | 1 | 5 | 4.95 | Radial | 132.5 | 50 | 6625
399-6797-ND | 385 | R46 | 1 | 5 | 5.15 | Radial | 132.5 | 50 | 6625
399-5870-ND | 27283 | R46 | 1 | 5 | 5.2 | Radial | 132.5 | 50 | 6625
399-12526-ND | 1207 | R71 | 1 | 5 | 5.2 | Radial | 132.5 | 50 | 6625
399-11839-ND | 393 | R46 | 1 | 5 | 5.25 | Radial | 132.5 | 50 | 6625
399-6795-ND | 772 | R46 | 1 | 5 | 5.35 | Radial | 132.5 | 50 | 6625
399-12706-ND | 812 | R46 | 1 | 5 | 5.35 | Radial | 132.5 | 50 | 6625
399-13457-ND | 180 | R71 | 1 | 5 | 5.95 | Radial | 132.5 | 50 | 6625
BC2614-ND | 1586 | MKP1839 HQ | 1.5 | 3 | 19.05 | Axial | 72 | 94.5 | 6804
BC3107-ND | 1603 | MKP1839 | 1 | 5 | 16.15 | Axial | 52.5 | 132.5 | 6956.25
P124082-ND | 636 | ECWFG | 1 | 5 | 5.05 | Radial | 135 | 52.5 | 7087.5
P124086-ND | 760 | ECWFG | 1 | 5 | 5.2 | Radial | 135 | 52.5 | 7087.5
P124090-ND | 650 | ECWFG | 1 | 5 | 5.3 | Radial | 135 | 52.5 | 7087.5
P124094-ND | 700 | ECWFG | 1 | 5 | 5.45 | Radial | 135 | 52.5 | 7087.5
478-9679-ND | 5480 | FV | 1 | 5 | 3.7 | Radial | 130 | 55 | 7150
732-5812-ND | 412 | WCAP-FTX2 | 1 | 5 | 6.9 | Radial | 130 | 55 | 7150
732-5912-ND | 179 | WCAP-FTX2 | 1 | 5 | 6.9 | Radial | 130 | 55 | 7150
399-5965-ND | 278 | PHE840E | 1 | 5 | 9 | Radial | 130 | 55 | 7150
399-5430-ND | 16023 | PHE840M | 1 | 5 | 9.45 | Radial | 130 | 55 | 7150
PCF1570-ND | 9669 | ECW-F(A) | 1 | 5 | 5.4 | Radial | 130 | 55.5 | 7215
399-19753-ND | 702 | R46 | 1 | 5 | 4.65 | Radial | 132.5 | 55 | 7287.5
399-19293-ND | 128 | R46 | 1 | 5 | 4.65 | Radial | 132.5 | 55 | 7287.5
399-20863-ND | 232 | R46 | 1 | 5 | 4.8 | Radial | 132.5 | 55 | 7287.5
399-9662-ND | 551 | R46 | 1 | 5 | 4.9 | Radial | 132.5 | 55 | 7287.5
399-18732-ND | 745 | R46 | 1 | 5 | 5.05 | Radial | 132.5 | 55 | 7287.5
399-12693-ND | 792 | R46 | 1 | 5 | 5.1 | Radial | 132.5 | 55 | 7287.5
399-11742-ND | 169 | R46 | 1 | 5 | 5.1 | Radial | 132.5 | 55 | 7287.5
495-2324-ND | 6433 | B32923 | 1 | 5 | 5.15 | Radial | 132.5 | 55 | 7287.5
495-6918-ND | 433 | B32923 | 1 | 5 | 5.15 | Radial | 132.5 | 55 | 7287.5
399-14809-ND | 753 | F863 | 1 | 5 | 5.5 | Radial | 132.5 | 55 | 7287.5
495-76980-1-ND | 590 | B32923 | 1 | 5 | 5.9 | Radial | 132.5 | 55 | 7287.5
495-6917-1-ND | 3 | B32923 | 1 | 5 | 5.9 | Radial | 132.5 | 55 | 7287.5
399-12746-ND | 938 | R71 | 1 | 5 | 5.95 | Radial | 132.5 | 55 | 7287.5
399-14823-1-ND | 1302 | F863 | 1 | 5 | 6.4 | Radial | 132.5 | 55 | 7287.5
1928-MKX2AW41005I00KSSD-ND | 29 | - | 1 | 5 | 6.45 | Radial | 132.5 | 55 | 7287.5
399-12753-ND | 678 | R75 | 1 | 5 | 7.85 | Radial | 132.5 | 55 | 7287.5
1928-1396-ND | 137 | - | 1 | 5 | 8.6 | Radial | 132.5 | 55 | 7287.5
399-7628-ND | 355 | R76 | 1 | 5 | 8.65 | Radial | 132.5 | 55 | 7287.5
495-6880-ND | 456 | B32653 | 1 | 5 | 9.15 | Radial | 132.5 | 55 | 7287.5
495-7061-ND | 1774 | B32653 | 1 | 5 | 9.8 | Radial | 132.5 | 55 | 7287.5
P12277-ND | 839 | ECW-F(L) | 1.1 | 4 | 8.96 | Radial | 112 | 65.2 | 7302.4
P12258-ND | 505 | ECW-F(L) | 1.1 | 4 | 10.84 | Radial | 112 | 65.2 | 7302.4
P12232-ND | 2059 | ECW-F(L) | 1 | 5 | 10.15 | Radial | 115 | 65 | 7475
P12207-ND | 546 | ECW-F(L) | 1 | 5 | 11.95 | Radial | 115 | 65 | 7475
P12278-ND | 1541 | ECW-F(L) | 1.2 | 4 | 9.2 | Radial | 112 | 68 | 7616
P12259-ND | 1099 | ECW-F(L) | 1.2 | 4 | 11.28 | Radial | 112 | 68 | 7616
338-4198-ND | 132 | 930C | 2 | 3 | 21.12 | Axial | 57.3 | 133.2 | 7632.36
1572-1271-ND | 1510 | MPR | 1 | 5 | 4.8 | Radial | 130 | 60 | 7800
1572-1798-ND | 1461 | MPX | 1 | 5 | 4.8 | Radial | 130 | 60 | 7800
P124127-ND | 598 | ECQ-UA | 1 | 5 | 5.25 | Radial | 130 | 60 | 7800
P14792-ND | 2682 | ECQ-UA | 1 | 5 | 5.5 | Radial | 130 | 60 | 7800
P124116-ND | 534 | ECQ-UA | 1 | 5 | 5.5 | Radial | 130 | 60 | 7800
P124149-ND | 600 | ECQ-UA | 1 | 5 | 6.05 | Radial | 130 | 60 | 7800
P124138-ND | 598 | ECQ-UA | 1 | 5 | 6.35 | Radial | 130 | 60 | 7800
338-4383-ND | 2099 | DPM | 1 | 5 | 10.75 | Radial | 130 | 60 | 7800
P12260-ND | 860 | ECW-F(L) | 1.3 | 4 | 11.72 | Radial | 112 | 70.4 | 7884.8
495-7041-ND | 604 | B32923 | 1 | 5 | 8.75 | Radial | 132.5 | 60 | 7950
1572-1020-ND | 1277 | MPW | 1 | 5 | 8.6 | Axial | 55 | 145 | 7975
1572-1353-ND | 498 | PHC | 2 | 3 | 17.1 | Axial | 60 | 138 | 8280
BC5055-ND | 3018 | F339X2 | 1 | 5 | 9.6 | Radial | 132.5 | 62.5 | 8281.25
BC3108-ND | 3 | MKP1839 | 1 | 5 | 18.1 | Axial | 62.5 | 132.5 | 8281.25
399-11705-ND | 9404 | F862 | 1 | 5 | 7.7 | Radial | 130 | 65 | 8450
399-12446-ND | 243 | R46 | 1 | 5 | 5.1 | Radial | 132.5 | 65 | 8612.5
399-13025-ND | 517 | R75L | 1 | 5 | 9.05 | Radial | 132.5 | 65 | 8612.5
399-11472-ND | 348 | PHE840M | 1 | 5 | 9 | Radial | 130 | 67.5 | 8775
338-4199-ND | 211 | 935C | 1 | 5 | 32.55 | Axial | 57 | 158.5 | 9034.5
399-13880-ND | 145 | C4G | 1.5 | 3 | 18.24 | Axial | 73.5 | 132 | 9702
338-1140-ND | 38 | 940C | 2 | 3 | 22.41 | Axial | 70.5 | 138 | 9729
399-17292-ND | 1065 | C4G | 1 | 5 | 17.6 | Axial | 60 | 165 | 9900
493-10197-ND | 232 | QAP | 1 | 5 | 18.5 | Axial | 127.5 | 79 | 10072.5
338-4371-ND | 147 | 930C | 1 | 5 | 20.45 | Axial | 65 | 160 | 10400
PF4105-ND | 5683 | ECW-F(B) | 1 | 5 | 3.95 | Radial | 140 | 75 | 10500
P12276-ND | 1637 | ECW-F(L) | 1 | 5 | 10.8 | Radial | 140 | 77.5 | 10850
P12257-ND | 964 | ECW-F(L) | 1 | 5 | 13.1 | Radial | 140 | 77.5 | 10850
1572-1272-ND | 463 | MPW | 1 | 5 | 9.45 | Axial | 65 | 170 | 11050
1572-1027-ND | 732 | PHC | 1 | 5 | 14.75 | Axial | 65 | 170 | 11050
399-13881-ND | 286 | C4G | 2 | 3 | 18.48 | Axial | 85.5 | 132 | 11286
BC3110-ND | 949 | MKP1839 HQ | 1 | 5 | 23 | Axial | 80 | 157.5 | 12600
338-1148-ND | 177 | 940C | 2 | 3 | 40.38 | Axial | 91.5 | 138 | 12627
338-1156-ND | 174 | 940C | 1.5 | 3 | 36.75 | Axial | 93 | 138 | 12834
338-3156-ND | 723 | 930C | 1 | 5 | 29.65 | Axial | 83 | 160 | 13280
338-1157-ND | 53 | 940C | 2 | 3 | 46.35 | Axial | 106.5 | 138 | 14697
1572-1021-ND | 72 | MPW | 1 | 5 | 13.15 | Axial | 87.5 | 170 | 14875
1572-1275-ND | 381 | PHC | 1 | 5 | 17.25 | Axial | 87.5 | 170 | 14875
338-3949-ND | 235 | 935C | 1 | 5 | 54.5 | Axial | 78.5 | 190.5 | 14954.25
BC2613-ND | 182 | MKP1839 HQ | 1 | 5 | 31.75 | Axial | 97.5 | 157.5 | 15356.25
338-1164-ND | 282 | 940C | 1.5 | 3 | 45.48 | Axial | 105 | 162 | 17010
338-1138-ND | 22 | 940C | 1 | 5 | 28.35 | Axial | 105 | 170 | 17850
1572-1354-ND | 80 | PPA | 2 | 3 | 44.88 | Axial | 117 | 165 | 19305
338-1171-ND | 344 | 940C | 1.5 | 3 | 59.16 | Axial | 126 | 162 | 20412
1572-1355-ND | 28 | PPA | 2 | 3 | 60.24 | Axial | 126 | 177 | 22302
399-13879-ND | 228 | C4G | 1 | 5 | 24.25 | Axial | 102.5 | 220 | 22550
338-1146-ND | 733 | 940C | 1 | 5 | 44.55 | Axial | 112.5 | 230 | 25875
399-4CAMUD4100AA1J-ND | 496 | C4C | 1 | 5 | 30.4 | Axial | 125 | 220 | 27500
338-1155-ND | 197 | 940C | 1 | 5 | 49.6 | Axial | 130 | 230 | 29900
1572-1276-ND | 95 | PPA | 1 | 5 | 42.65 | Axial | 160 | 230 | 36800
338-1163-ND | 904 | 940C | 1 | 5 | 57.7 | Axial | 165 | 230 | 37950
338-4373-ND | 22 | 942C | 1 | 5 | 57.65 | Axial | 150 | 270 | 40500
338-1170-ND | 52 | 940C | 1 | 5 | 74.8 | Axial | 195 | 230 | 44850
338-1182-ND | 2265 | 940C | 1 | 5 | 85.8 | Axial | 205 | 270 | 55350
P122595-ND | 438 | ECW-F(D) | 2.2 | 2 | 2.9 | Radial | #VALUE! | #VALUE! | #VALUE!
P122571-ND | 372 | ECW-F(D) | 2.2 | 2 | 3.06 | Radial | #VALUE! | #VALUE! | #VALUE!
P122596-ND | 221 | ECW-F(D) | 2.7 | 2 | 3.32 | Radial | #VALUE! | #VALUE! | #VALUE!
P122572-ND | 457 | ECW-F(D) | 2.7 | 2 | 3.52 | Radial | #VALUE! | #VALUE! | #VALUE!
399-463N410050M1K-ND | 398 | R46 | 1 | 5 | 5 | Radial | #VALUE! | #VALUE! | #VALUE!

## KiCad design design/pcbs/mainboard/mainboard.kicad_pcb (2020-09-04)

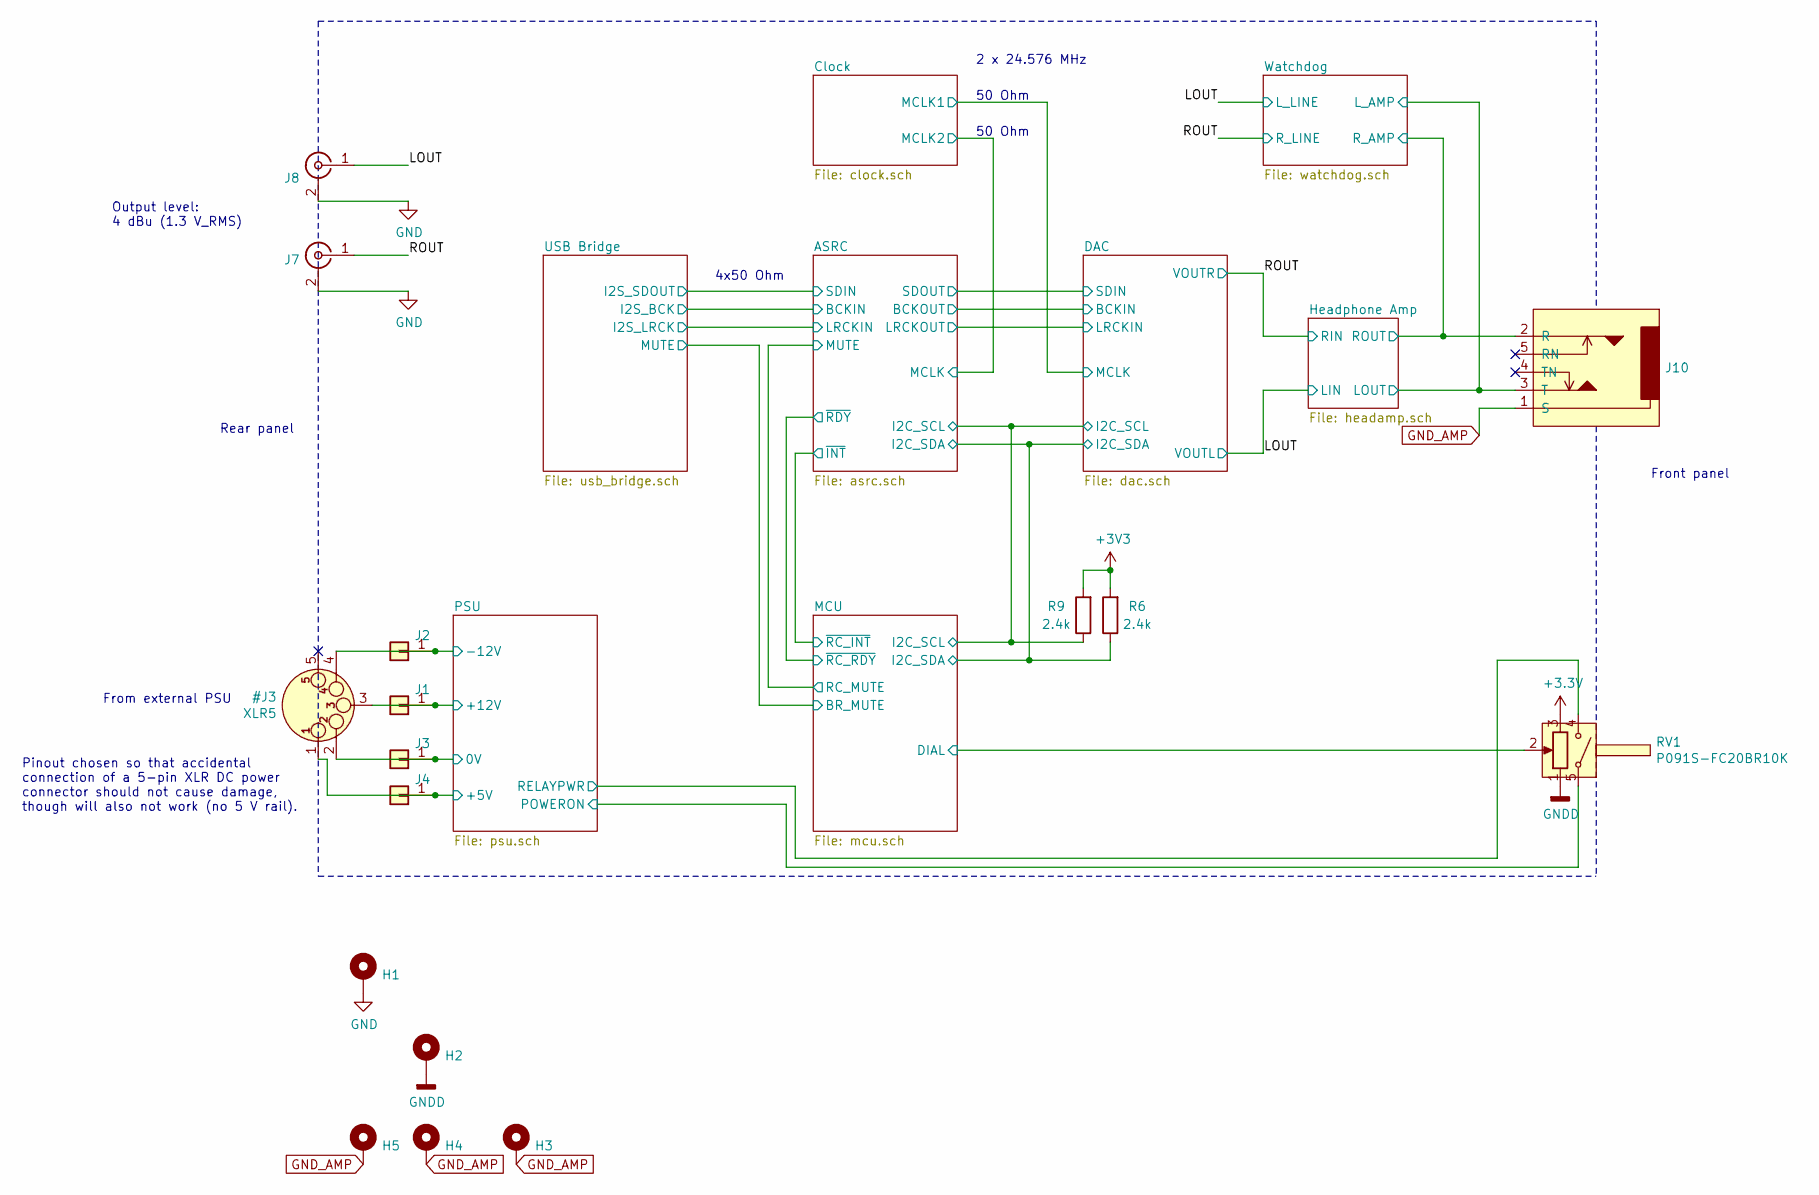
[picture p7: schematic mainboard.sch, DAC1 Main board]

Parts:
H1, H2, H3, H4, H5: MountingHole; MountingHole_3.2mm_M3_Pad_Via
J1, J2, J3, J4: Conn_01x01; SolderWirePad_1x01_Drill1.5mm
J7: Conn_Coaxial; SolderWirePad_1x02_P5.08mm_Drill1.5mm; DigiKey SC1828-ND
J8: Conn_Coaxial; SolderWirePad_1x02_P5.08mm_Drill1.5mm; DigiKey SC2440-ND
J10: AudioJackSw; Amphenol_ACJS-MHOM; DigiKey 889-1818-ND
R6, R9: 2.4k; R_0402_1005Metric; LCSC C25882
RV1: P091S-FC20BR10K; DigiKey 987-1283-ND

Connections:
/ASRC/I2C_SCL: R9.1; also elsewhere on the board
/ASRC/I2C_SDA: R6.1; also elsewhere on the board
/Headphone Amp/LOUT: J10.3 (T); also elsewhere on the board
/Headphone Amp/ROUT: J10.2 (R); also elsewhere on the board
/LOUT: J8.1 (In); also elsewhere on the board
/MCU/DIAL: RV1.2; also elsewhere on the board
/PSU/POWERON: RV1.5; also elsewhere on the board
/ROUT: J7.1 (In); also elsewhere on the board
GNDD: H2.1, RV1.1; also elsewhere on the board
GND_AMP: H3.1, H4.1, H5.1, J10.1 (S), J10.6 (S); also elsewhere on the board

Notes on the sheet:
50 Ohm
2 x 24.576 MHz
From external PSU
Rear panel
Front panel
Pinout chosen so that accidental connection of a 5-pin XLR DC power connector should not cause damage, though will also not work (no 5 V rail).
Output level: 4 dBu (1.3 V_RMS)
4x50 Ohm

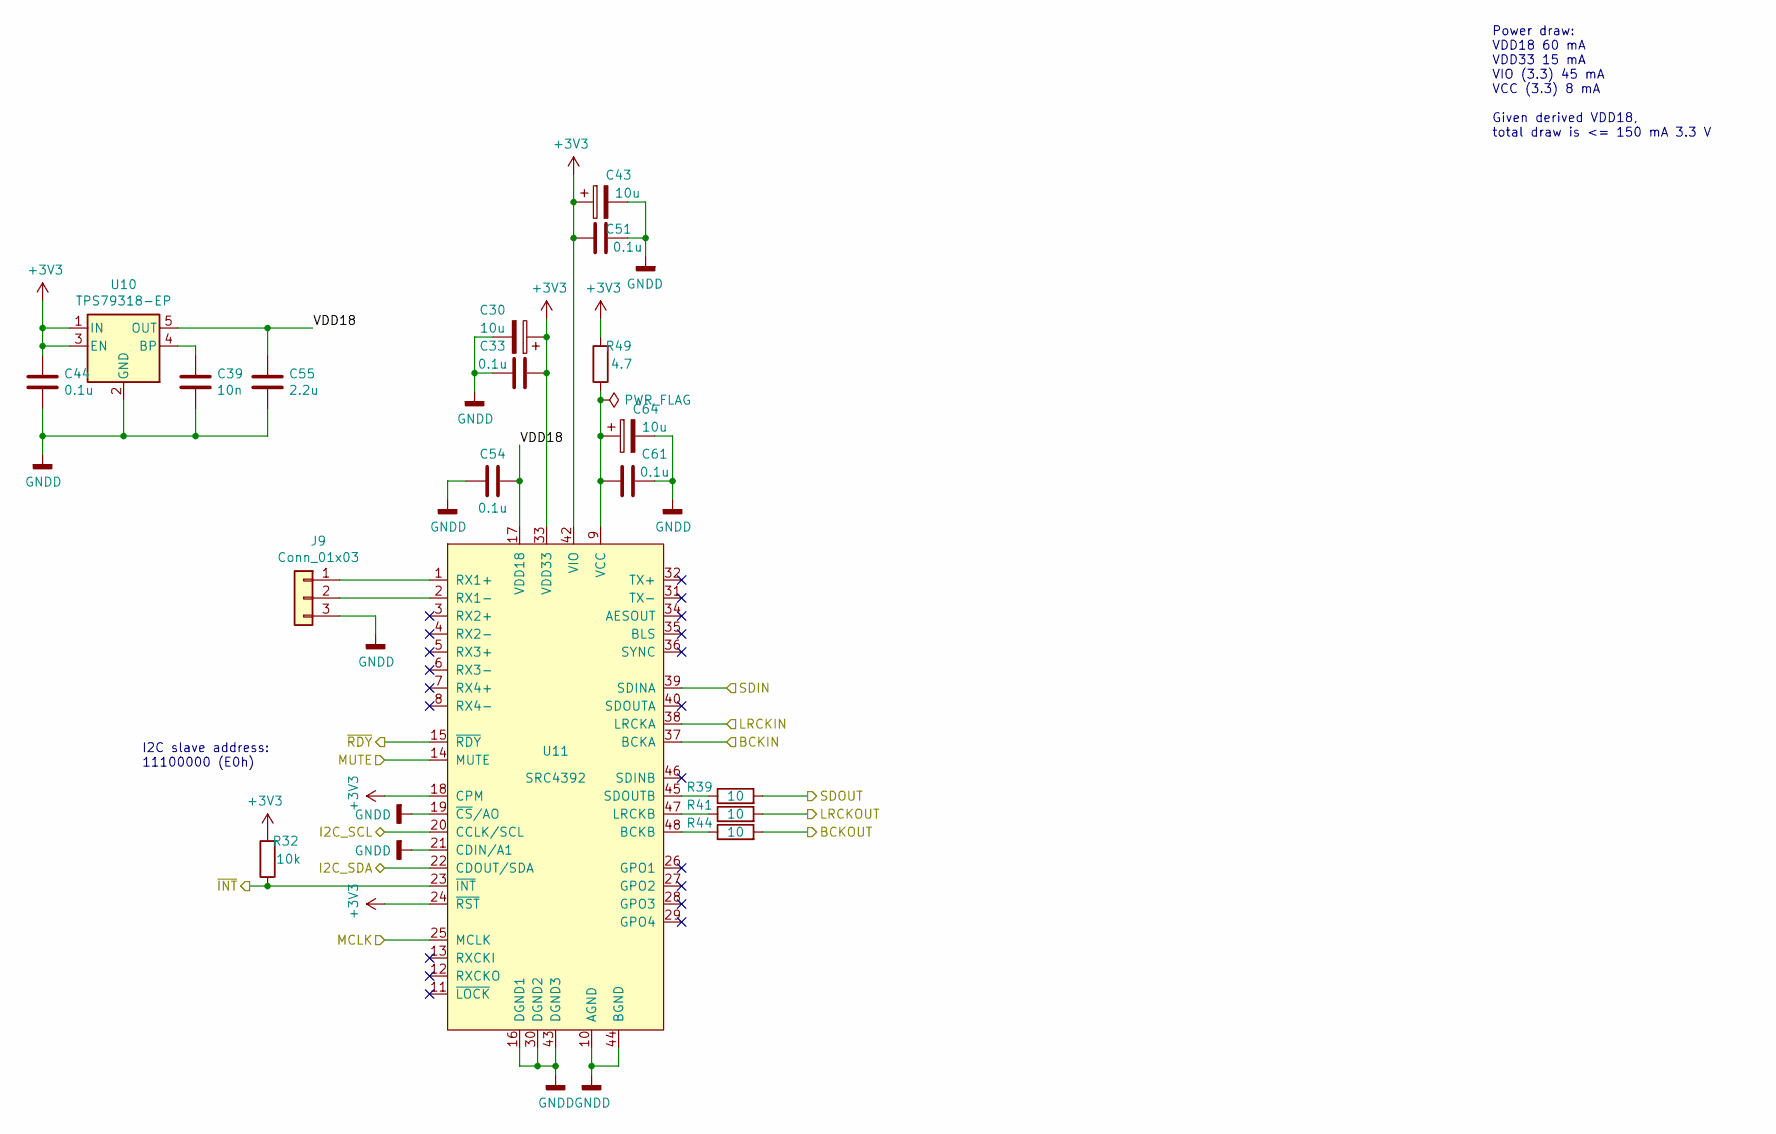
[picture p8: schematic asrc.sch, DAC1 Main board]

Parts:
C30, C43, C64: 10u; CP_EIA-3216-18_Kemet-A; LCSC C7171
C33, C44, C51, C54, C61: 0.1u; C_0603_1608Metric; LCSC C14663
C39: 10n; C_0402_1005Metric; LCSC C15195
C55: 2.2u; C_0603_1608Metric; LCSC C23630
J9: Conn_01x03; PinHeader_1x03_P2.54mm_Vertical
R32: 10k; R_0402_1005Metric; LCSC C25744
R39, R41, R44: 10; R_0402_1005Metric; LCSC C25077
R49: 4.7; R_0603_1608Metric; DigiKey 408-1436-1-ND
U10: TPS79318-EP; SOT-23-5; DigiKey 296-12155-1-ND
U11: SRC4392; TQFP-48_7x7mm_P0.5mm; DigiKey 296-19740-1-ND

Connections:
/ASRC/BCKIN: U11.37 (BCKA); also elsewhere on the board
/ASRC/I2C_SCL: U11.20 (CCLK/SCL); also elsewhere on the board
/ASRC/I2C_SDA: U11.22 (CDOUT/SDA); also elsewhere on the board
/ASRC/MCLK: U11.25 (MCLK); also elsewhere on the board
/ASRC/MUTE: U11.14 (MUTE); also elsewhere on the board
/ASRC/VDD18: C54.1, C55.1, U10.5 (OUT), U11.17 (VDD18)
/ASRC/~INT: R32.1, U11.23 (~INT); also elsewhere on the board
/DAC/BCKIN: R44.2; also elsewhere on the board
/DAC/LRCKIN: R41.2; also elsewhere on the board
/DAC/SDIN: R39.2; also elsewhere on the board
/MCU/~RC_RDY: U11.15 (~RDY); also elsewhere on the board
/USB Bridge/I2S_LRCK: U11.38 (LRCKA); also elsewhere on the board
/USB Bridge/I2S_SDOUT: U11.39 (SDINA); also elsewhere on the board
GNDD: C30.2, C33.2, C39.2, C43.2, C44.2, C51.2, C54.2, C55.2, C61.1, C64.2, J9.3, U10.2 (GND), U11.10 (AGND), U11.16 (DGND1), U11.19 (~CS~/AO), U11.21 (CDIN/A1), U11.30 (DGND2), U11.43 (DGND3), U11.44 (BGND); also elsewhere on the board
unnamed: C39.1, U10.4 (BP)
unnamed: C61.2, C64.1, R49.1, U11.9 (VCC)
unnamed: J9.1, U11.1 (RX1+)
unnamed: J9.2, U11.2 (RX1-)
unnamed: R39.1, U11.45 (SDOUTB)
unnamed: R41.1, U11.47 (LRCKB)
unnamed: R44.1, U11.48 (BCKB)

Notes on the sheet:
I2C slave address: 11100000 (E0h)
Power draw: VDD18 60 mA VDD33 15 mA VIO (3.3) 45 mA VCC (3.3) 8 mA Given derived VDD18, total draw is <= 150 mA 3.3 V

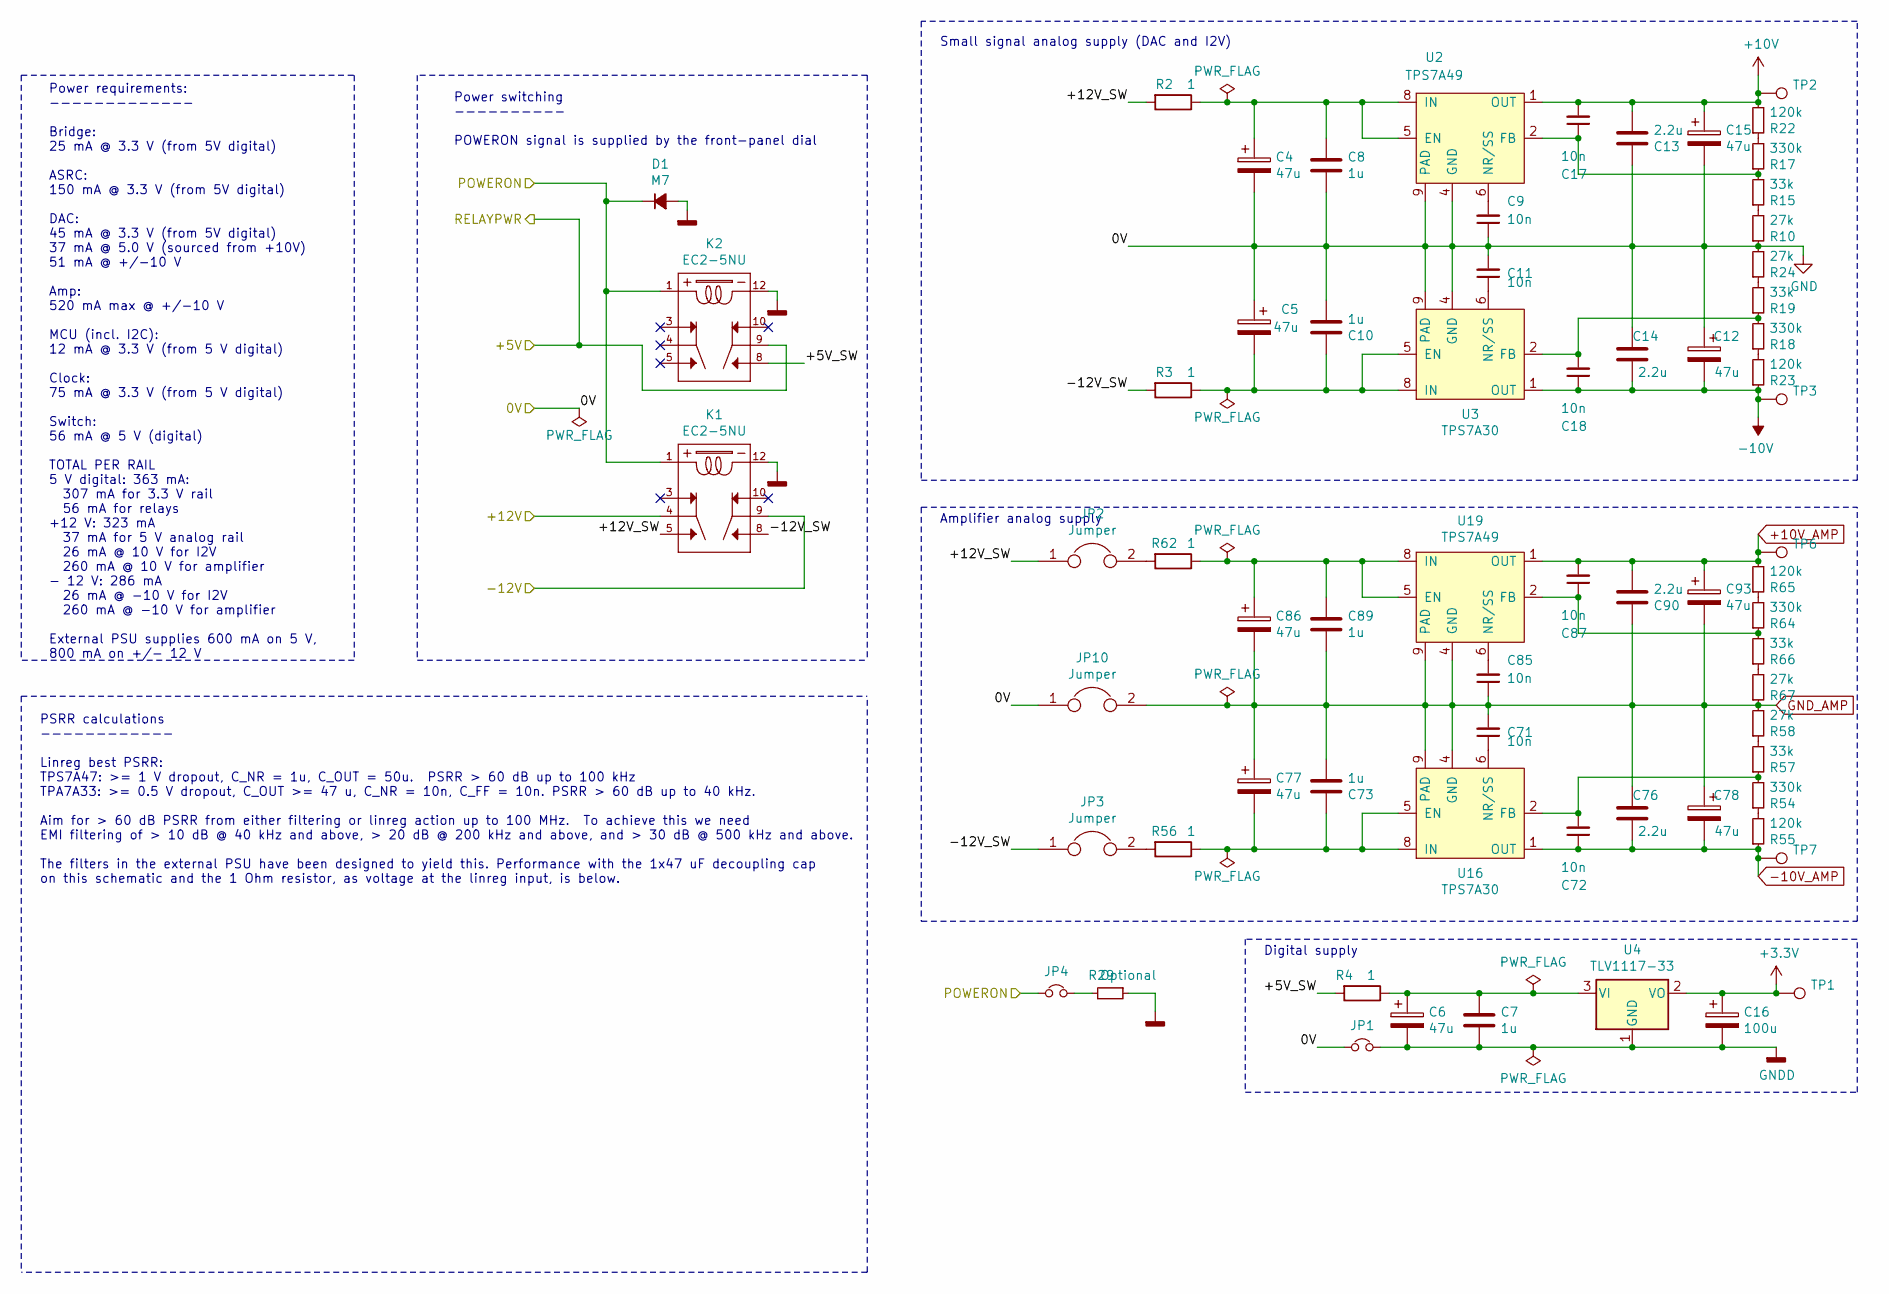
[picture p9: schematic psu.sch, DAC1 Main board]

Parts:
C4, C5, C6, C12, C15, C77, C78, C86, C93: 47u; CP_Radial_D8.0mm_P3.50mm; DigiKey 732-6324-1-ND
C7, C8, C10, C73, C89: 1u; C_0805_2012Metric; LCSC C28323
C9, C11, C17, C18, C71, C72, C85, C87: 10n; C_0603_1608Metric; LCSC C14663
C13, C14, C76, C90: 2.2u; C_1206_3216Metric; LCSC C50254
C16: 100u; CP_Radial_D8.0mm_P3.50mm; DigiKey 1572-1662-ND
D1: M7; D_SOD-123F; LCSC C64898
JP1: Jumper_NC_Small; SolderJumper-2_P1.3mm_Bridged2Bar_Pad1.0x1.5mm
JP2, JP3: Jumper; PinHeader_1x02_P2.54mm_Vertical
JP4: PinHeader_1x02_P2.54mm_Vertical
JP10: Jumper; SolderJumper-2_P1.3mm_Bridged2Bar_Pad1.0x1.5mm
K1, K2: EC2-5NU; RELAY_EC2-5NU; DigiKey 399-11052-5-ND
R2, R3, R4, R56, R62: 1; R_1206_3216Metric; LCSC C17928
R10, R24, R58, R67: 27k; R_0402_1005Metric; LCSC C25771
R15, R19, R57, R66: 33k; R_0402_1005Metric; LCSC C25779
R17, R18, R54, R64: 330k; R_0402_1005Metric; LCSC C25778
R22, R23, R55, R65: 120k; R_0402_1005Metric; LCSC C25750
R29: Optional; R_Axial_DIN0204_L3.6mm_D1.6mm_P5.08mm_Horizontal
TP1, TP2, TP3, TP6, TP7: TestPoint; TestPoint_THTPad_D3.0mm_Drill1.5mm
U2, U19: TPS7A49; MSOP-8-1EP_3x3mm_P0.65mm_EP1.68x1.88mm_ThermalVias; DigiKey 296-27751-1-ND
U3, U16: TPS7A30; MSOP-8-1EP_3x3mm_P0.65mm_EP1.68x1.88mm_ThermalVias; DigiKey 296-27750-1-ND
U4: TLV1117-33; SOT-223-3_TabPin2; DigiKey 296-28778-1-ND

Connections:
+10V: C13.2, C15.1, C17.2, R22.2, TP2.1, U2.1 (OUT); also elsewhere on the board
+10V_AMP: C87.2, C90.2, C93.1, R65.2, TP6.1, U19.1 (OUT); also elsewhere on the board
-10V: C12.2, C14.2, C18.1, R23.1, TP3.1, U3.1 (OUT); also elsewhere on the board
-10V_AMP: C72.1, C76.2, C78.2, R55.1, TP7.1, U16.1 (OUT); also elsewhere on the board
/PSU/+5V_SW: K2.8, R4.2
/PSU/+12V_SW: JP2.1, K1.5, R2.2
/PSU/-12V_SW: JP3.1, K1.8, R3.2
/PSU/POWERON: D1.1 (K), JP4.1, K1.1, K2.1; also elsewhere on the board
GNDD: C6.2, C7.2, C16.2, D1.2 (A), JP1.2, K1.12, K2.12, R29.1, U4.1 (GND); also elsewhere on the board
GND_AMP: C71.2, C73.2, C76.1, C77.1, C78.1, C85.1, C86.2, C89.2, C90.1, C93.2, JP10.2, R58.2, R67.1, U16.4 (GND), U16.9 (PAD), U19.4 (GND), U19.9 (PAD); also elsewhere on the board
unnamed: C4.1, C8.1, R2.1, U2.5 (EN), U2.8 (IN)
unnamed: C6.1, C7.1, R4.1, U4.3 (VI)
unnamed: C9.2, U2.6 (NR/SS)
unnamed: C5.2, C10.1, R3.1, U3.5 (EN), U3.8 (IN)
unnamed: C11.1, U3.6 (NR/SS)
unnamed: C17.1, R15.2, R17.1, U2.2 (FB)
unnamed: C18.2, R18.2, R19.1, U3.2 (FB)
unnamed: C71.1, U16.6 (NR/SS)
unnamed: C72.2, R54.2, R57.1, U16.2 (FB)
unnamed: C73.1, C77.2, R56.1, U16.5 (EN), U16.8 (IN)
unnamed: C85.2, U19.6 (NR/SS)
unnamed: C86.1, C89.1, R62.1, U19.5 (EN), U19.8 (IN)
unnamed: C87.1, R64.1, R66.2, U19.2 (FB)
unnamed: JP2.2, R62.2
unnamed: JP3.2, R56.2
unnamed: JP4.2, R29.2
unnamed: R10.2, R15.1
unnamed: R17.2, R22.1
unnamed: R18.1, R23.2
unnamed: R19.2, R24.1
unnamed: R54.1, R55.2
unnamed: R57.2, R58.1
unnamed: R64.2, R65.1
unnamed: R66.1, R67.2

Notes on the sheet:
PSRR calculations ------------ Linreg best PSRR: TPS7A47: >= 1 V dropout, C_NR = 1u, C_OUT = 50u. PSRR > 60 dB up to 100 kHz TPA7A33: >= 0.5 V dropout, C_OUT >= 47 u, C_NR = 10n, C_FF = 10n. PSRR > 60 dB up to 40 kHz. Aim for > 60 dB PSRR from either filtering or linreg action up to 100 MHz. To ach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
Power switching ---------- POWERON signal is supplied by the front-panel dial
Power requirements: ------------- Bridge: 25 mA @ 3.3 V (from 5V digital) ASRC: 150 mA @ 3.3 V (from 5V digital) DAC: 45 mA @ 3.3 V (from 5V digital) 37 mA @ 5.0 V (sourced from +10V) 51 mA @ +/-10 V Amp: 520 mA max @ +/-10 V MCU (incl. I2C): 12 mA @ 3.3 V (from 5 V digital) Clock: 75 mA @ 3.3 V (f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
Small signal analog supply (DAC and I2V)
Amplifier analog supply
Digital supply

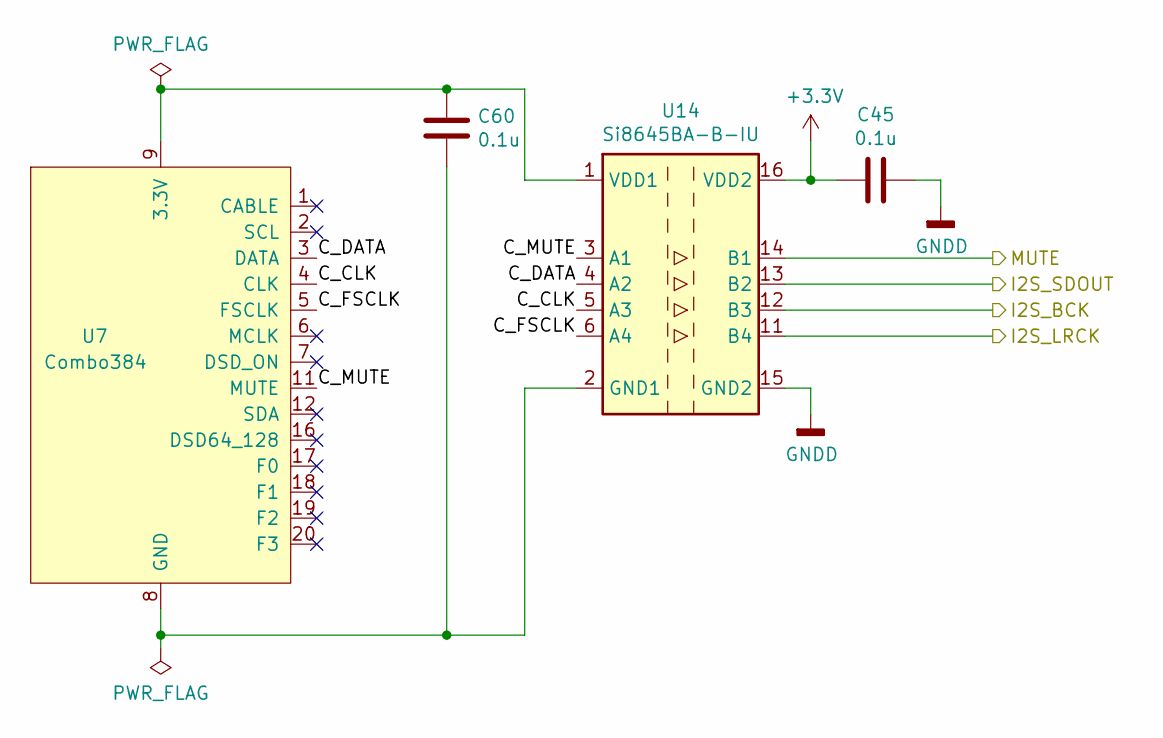
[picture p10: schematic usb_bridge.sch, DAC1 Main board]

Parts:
C45, C60: 0.1u; C_0603_1608Metric; LCSC C14663
U7: Combo384; AmaneroCombo384
U14: Si8645BA-B-IU; QSOP-16_3.9x4.9mm_P0.635mm; DigiKey 336-2096-5-ND

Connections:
/ASRC/BCKIN: U14.12 (B3); also elsewhere on the board
/MCU/BR_MUTE: U14.14 (B1); also elsewhere on the board
/USB Bridge/C_CLK: U7.4 (CLK), U14.5 (A3)
/USB Bridge/C_DATA: U7.3 (DATA), U14.4 (A2)
/USB Bridge/C_FSCLK: U7.5 (FSCLK), U14.6 (A4)
/USB Bridge/C_MUTE: U7.11 (MUTE), U14.3 (A1)
/USB Bridge/I2S_LRCK: U14.11 (B4); also elsewhere on the board
/USB Bridge/I2S_SDOUT: U14.13 (B2); also elsewhere on the board
GNDD: C45.1, U14.9 (GND2), U14.15 (GND2); also elsewhere on the board
unnamed: C60.1, U7.9 (3.3V), U7.10 (3.3V), U14.1 (VDD1)
unnamed: C60.2, U7.8 (GND), U7.13 (GND), U7.14 (GND), U7.15 (GND), U14.2 (GND1), U14.8 (GND1)

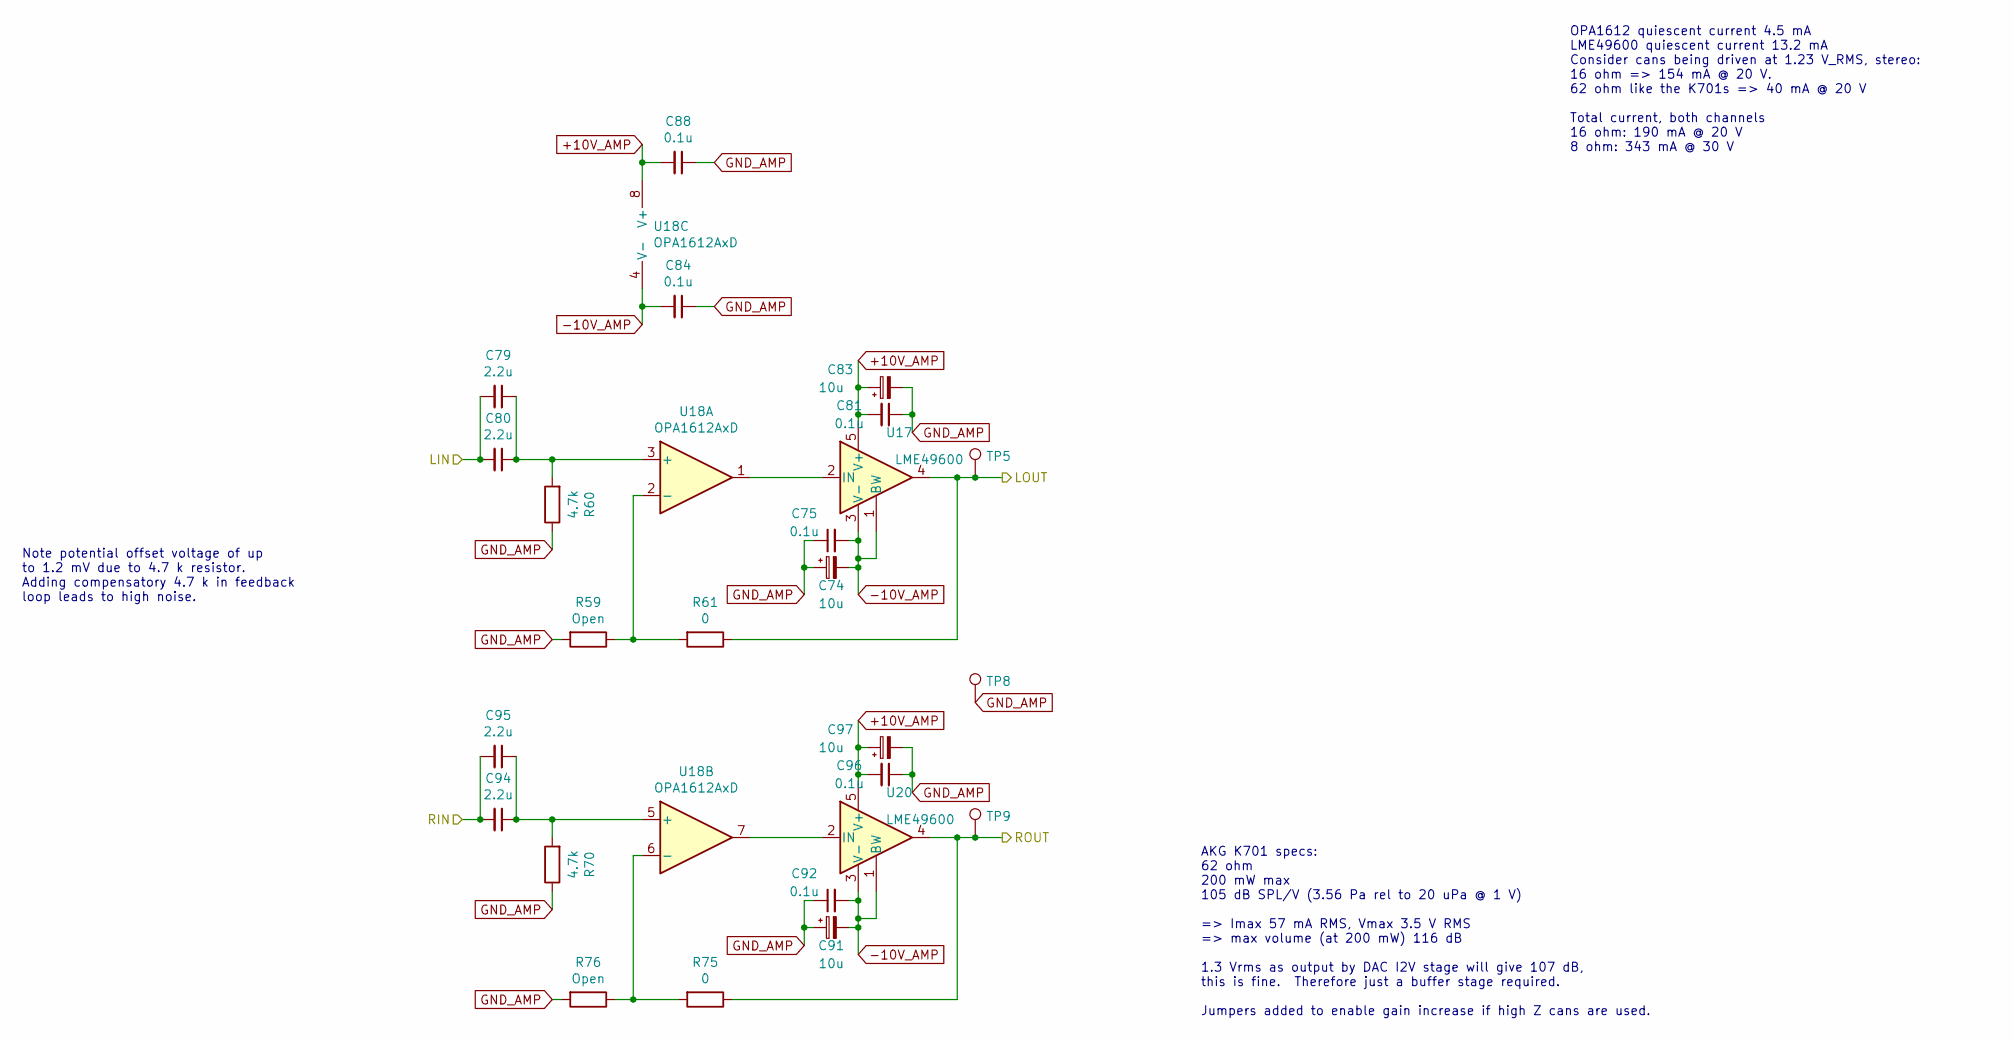
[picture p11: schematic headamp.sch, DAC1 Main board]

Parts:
C74, C83, C91, C97: 10u; CP_EIA-3216-18_Kemet-A; LCSC C7171
C75, C81, C84, C88, C92, C96: 0.1u; C_0603_1608Metric; LCSC C14663
C79, C80, C94, C95: 2.2u; C_Rect_L18.0mm_W11.0mm_P15.00mm_FKS3_FKP3; DigiKey 732-11840-ND
R59, R76: Open; R_Axial_DIN0207_L6.3mm_D2.5mm_P10.16mm_Horizontal
R60, R70: 4.7k; R_0603_1608Metric; DigiKey RG16P4.7KBCT-ND
R61, R75: 0; R_Axial_DIN0207_L6.3mm_D2.5mm_P10.16mm_Horizontal
TP5, TP8, TP9: TestPoint; TestPoint_THTPad_D3.0mm_Drill1.5mm
U17, U20: LME49600; TO-263-5_TabPin3; DigiKey 296-43968-5-ND
U18: OPA1612AxD; SOIC-8_3.9x4.9mm_P1.27mm; DigiKey 296-39098-1-ND

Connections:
+10V_AMP: C81.2, C83.1, C88.2, C96.2, C97.1, U17.5 (V+), U18.8 (V+), U20.5 (V+); also elsewhere on the board
-10V_AMP: C74.2, C75.2, C84.2, C91.2, C92.2, U17.1 (BW), U17.3 (V-), U18.4 (V-), U20.1 (BW), U20.3 (V-); also elsewhere on the board
/Headphone Amp/LOUT: R61.1, TP5.1, U17.4; also elsewhere on the board
/Headphone Amp/ROUT: R75.1, TP9.1, U20.4; also elsewhere on the board
/LOUT: C79.2, C80.2; also elsewhere on the board
/ROUT: C94.2, C95.2; also elsewhere on the board
GND_AMP: C74.1, C75.1, C81.1, C83.2, C84.1, C88.1, C91.1, C92.1, C96.1, C97.2, R59.2, R60.1, R70.1, R76.2, TP8.1; also elsewhere on the board
unnamed: C79.1, C80.1, R60.2, U18.3 (+)
unnamed: C94.1, C95.1, R70.2, U18.5 (+)
unnamed: R59.1, R61.2, U18.2 (-)
unnamed: R75.2, R76.1, U18.6 (-)
unnamed: U17.2 (IN), U18.1
unnamed: U18.7, U20.2 (IN)

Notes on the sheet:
AKG K701 specs: 62 ohm 200 mW max 105 dB SPL/V (3.56 Pa rel to 20 uPa @ 1 V) => Imax 57 mA RMS, Vmax 3.5 V RMS => max volume (at 200 mW) 116 dB 1.3 Vrms as output by DAC I2V stage will give 107 dB, this is fine. Therefore just a buffer stage required. Jumpers added to enable gain increase if high Z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
OPA1612 quiescent current 4.5 mA LME49600 quiescent current 13.2 mA Consider cans being driven at 1.23 V_RMS, stereo: 16 ohm => 154 mA @ 20 V. 62 ohm like the K701s => 40 mA @ 20 V Total current, both channels 16 ohm: 190 mA @ 20 V 8 ohm: 343 mA @ 30 V
Note potential offset voltage of up to 1.2 mV due to 4.7 k resistor. Adding compensatory 4.7 k in feedback loop leads to high noise.

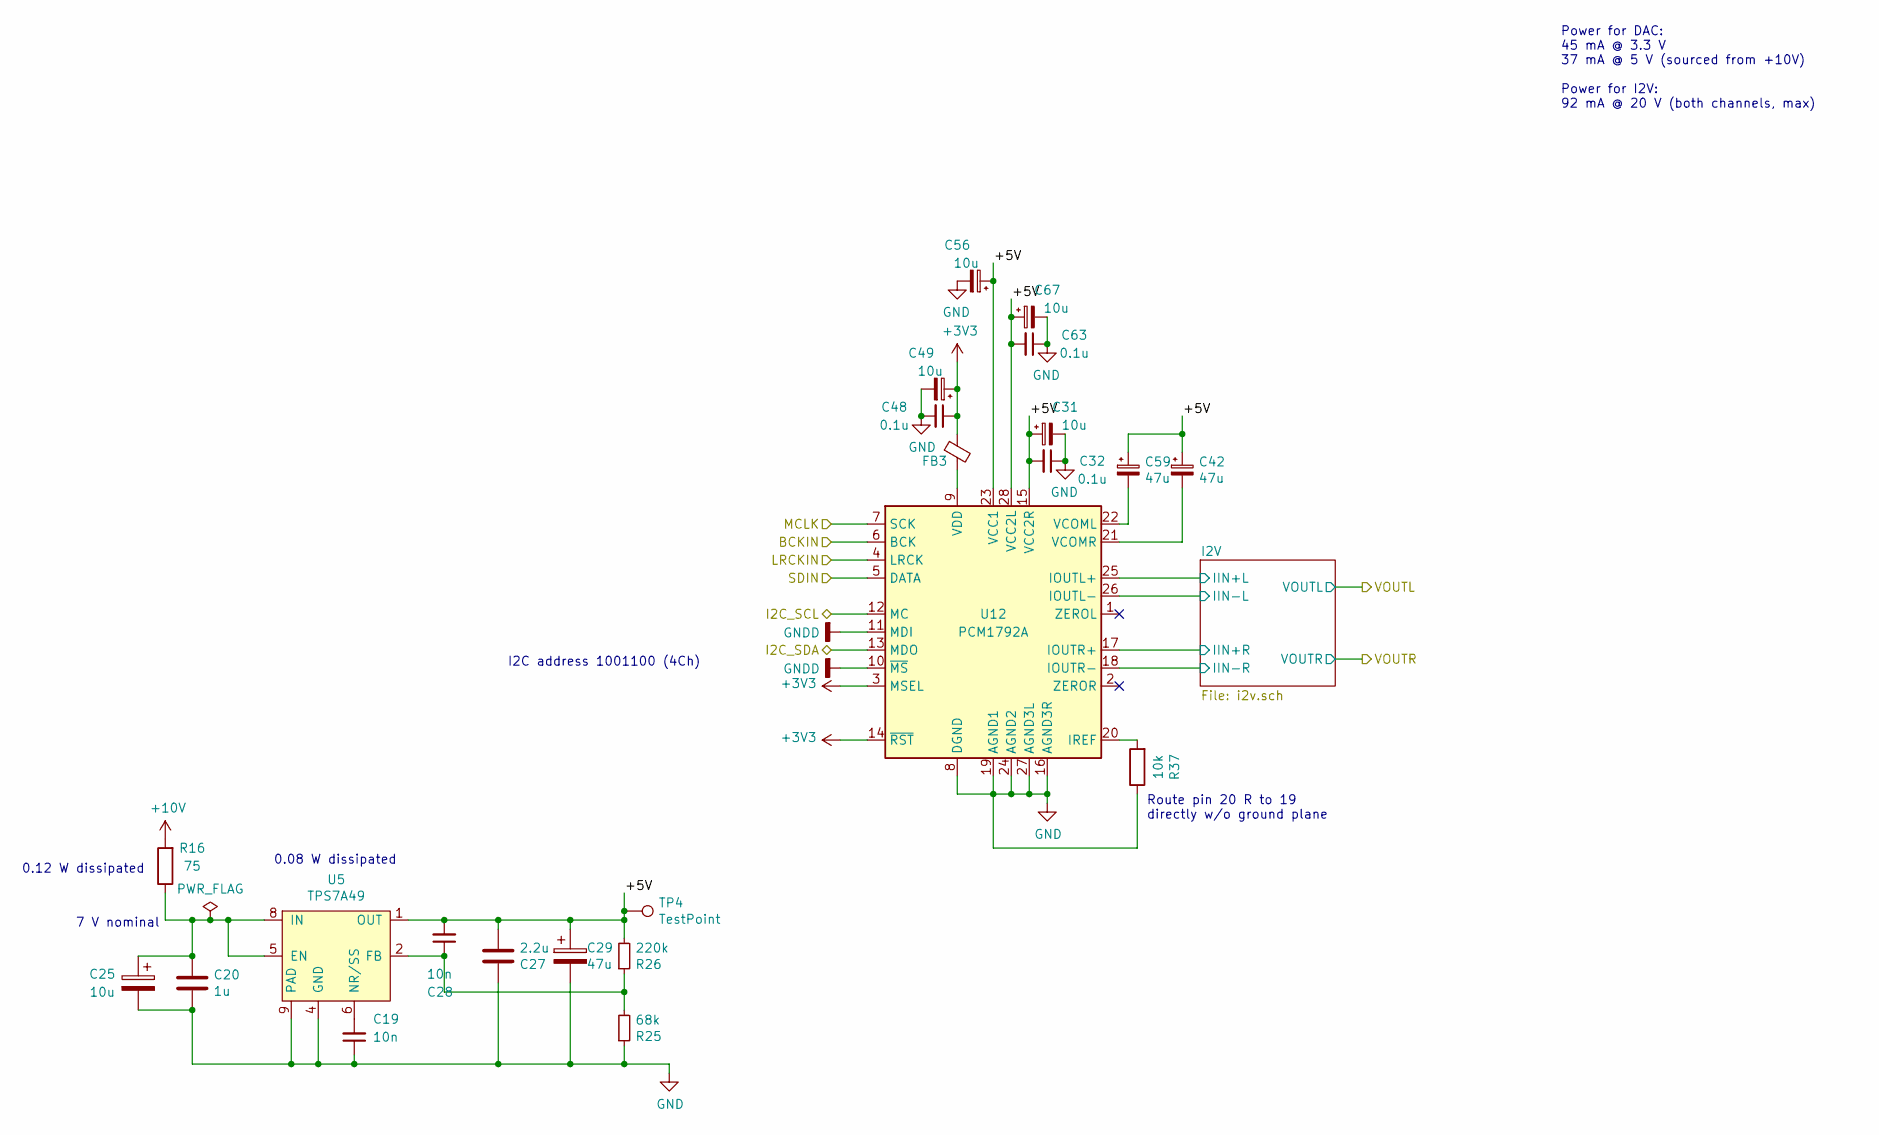
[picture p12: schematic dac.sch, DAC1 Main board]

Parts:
C19, C28: 10n; C_0603_1608Metric; LCSC C14663
C20: 1u; C_0805_2012Metric; LCSC C28323
C25, C31, C49, C56, C67: 10u; CP_EIA-3216-18_Kemet-A; LCSC C7171
C27: 2.2u; C_1206_3216Metric; LCSC C50254
C29: 47u; CP_Radial_D5.0mm_P2.00mm; DigiKey 732-9306-1-ND
C32, C48, C63: 0.1u; C_0603_1608Metric; LCSC C14663
C42, C59: 47u; CP_Radial_D6.3mm_P2.50mm; DigiKey 493-15014-ND
FB3: Ferrite_Bead_Small; R_0603_1608Metric_Pad1.05x0.95mm_HandSolder
R16: 75; R_1206_3216Metric; LCSC C17985
R25: 68k; R_0402_1005Metric; LCSC C36871
R26: 220k; R_0402_1005Metric; LCSC C25767
R37: 10k; R_0402_1005Metric; DigiKey RG10P10.0KDCT-ND
TP4: TestPoint; TestPoint_THTPad_D3.0mm_Drill1.5mm
U5: TPS7A49; MSOP-8-1EP_3x3mm_P0.65mm_EP1.68x1.88mm_ThermalVias; DigiKey 296-27751-1-ND
U12: PCM1792A; SSOP-28_5.3x10.2mm_P0.65mm; DigiKey 296-26303-5-ND

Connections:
+10V: R16.2; also elsewhere on the board
/ASRC/I2C_SCL: U12.12 (MC); also elsewhere on the board
/ASRC/I2C_SDA: U12.13 (MDO); also elsewhere on the board
/DAC/+5V: C27.2, C28.2, C29.1, C31.1, C32.2, C42.1, C56.1, C59.1, C63.2, C67.1, R26.2, TP4.1, U5.1 (OUT), U12.15 (VCC2R), U12.23 (VCC1), U12.28 (VCC2L)
/DAC/BCKIN: U12.6 (BCK); also elsewhere on the board
/DAC/I2V/IIN+L: U12.25 (IOUTL+); also elsewhere on the board
/DAC/I2V/IIN+R: U12.17 (IOUTR+); also elsewhere on the board
/DAC/I2V/IIN-L: U12.26 (IOUTL-); also elsewhere on the board
/DAC/I2V/IIN-R: U12.18 (IOUTR-); also elsewhere on the board
/DAC/LRCKIN: U12.4 (LRCK); also elsewhere on the board
/DAC/MCLK: U12.7 (SCK); also elsewhere on the board
/DAC/SDIN: U12.5 (DATA); also elsewhere on the board
GNDD: U12.10 (~MS), U12.11 (MDI); also elsewhere on the board
unnamed: C19.2, U5.6 (NR/SS)
unnamed: C20.1, C25.1, R16.1, U5.5 (EN), U5.8 (IN)
unnamed: C28.1, R25.2, R26.1, U5.2 (FB)
unnamed: C42.2, U12.21 (VCOMR)
unnamed: C59.2, U12.22 (VCOML)
unnamed: FB3.2, U12.9 (VDD)
unnamed: R37.2, U12.20 (IREF)

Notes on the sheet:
Power for DAC: 45 mA @ 3.3 V 37 mA @ 5 V (sourced from +10V) Power for I2V: 92 mA @ 20 V (both channels, max)
I2C address 1001100 (4Ch)
0.08 W dissipated
Route pin 20 R to 19 directly w/o ground plane
0.12 W dissipated
7 V nominal

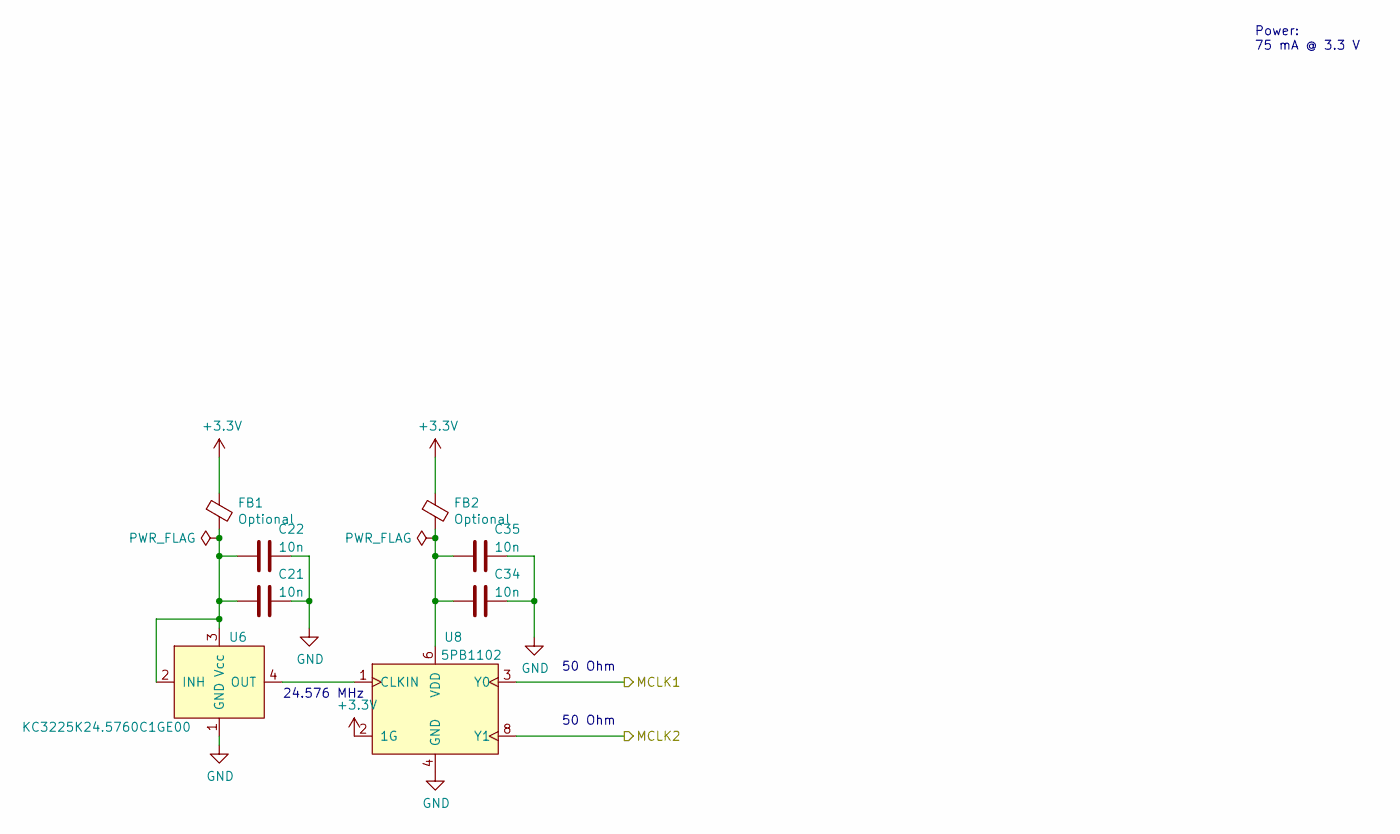
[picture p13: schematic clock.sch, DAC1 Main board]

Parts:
C21, C22, C34, C35: 10n; C_0603_1608Metric; LCSC C14663
FB1, FB2: Optional; R_0603_1608Metric_Pad1.05x0.95mm_HandSolder
U6: KC3225K24.5760C1GE00; Crystal_SMD_3225-4Pin_3.2x2.5mm; DigiKey 1253-1407-1-ND
U8: 5PB1102; TSSOP-8_4.4x3mm_P0.65mm; DigiKey 800-2889-5-ND

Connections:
/ASRC/MCLK: U8.8 (Y1); also elsewhere on the board
/DAC/MCLK: U8.3 (Y0); also elsewhere on the board
unnamed: C21.2, C22.2, FB1.2, U6.2 (INH), U6.3 (Vcc)
unnamed: C34.2, C35.2, FB2.2, U8.6 (VDD)
unnamed: U6.4 (OUT), U8.1 (CLKIN)

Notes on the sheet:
24.576 MHz
50 Ohm
Power: 75 mA @ 3.3 V

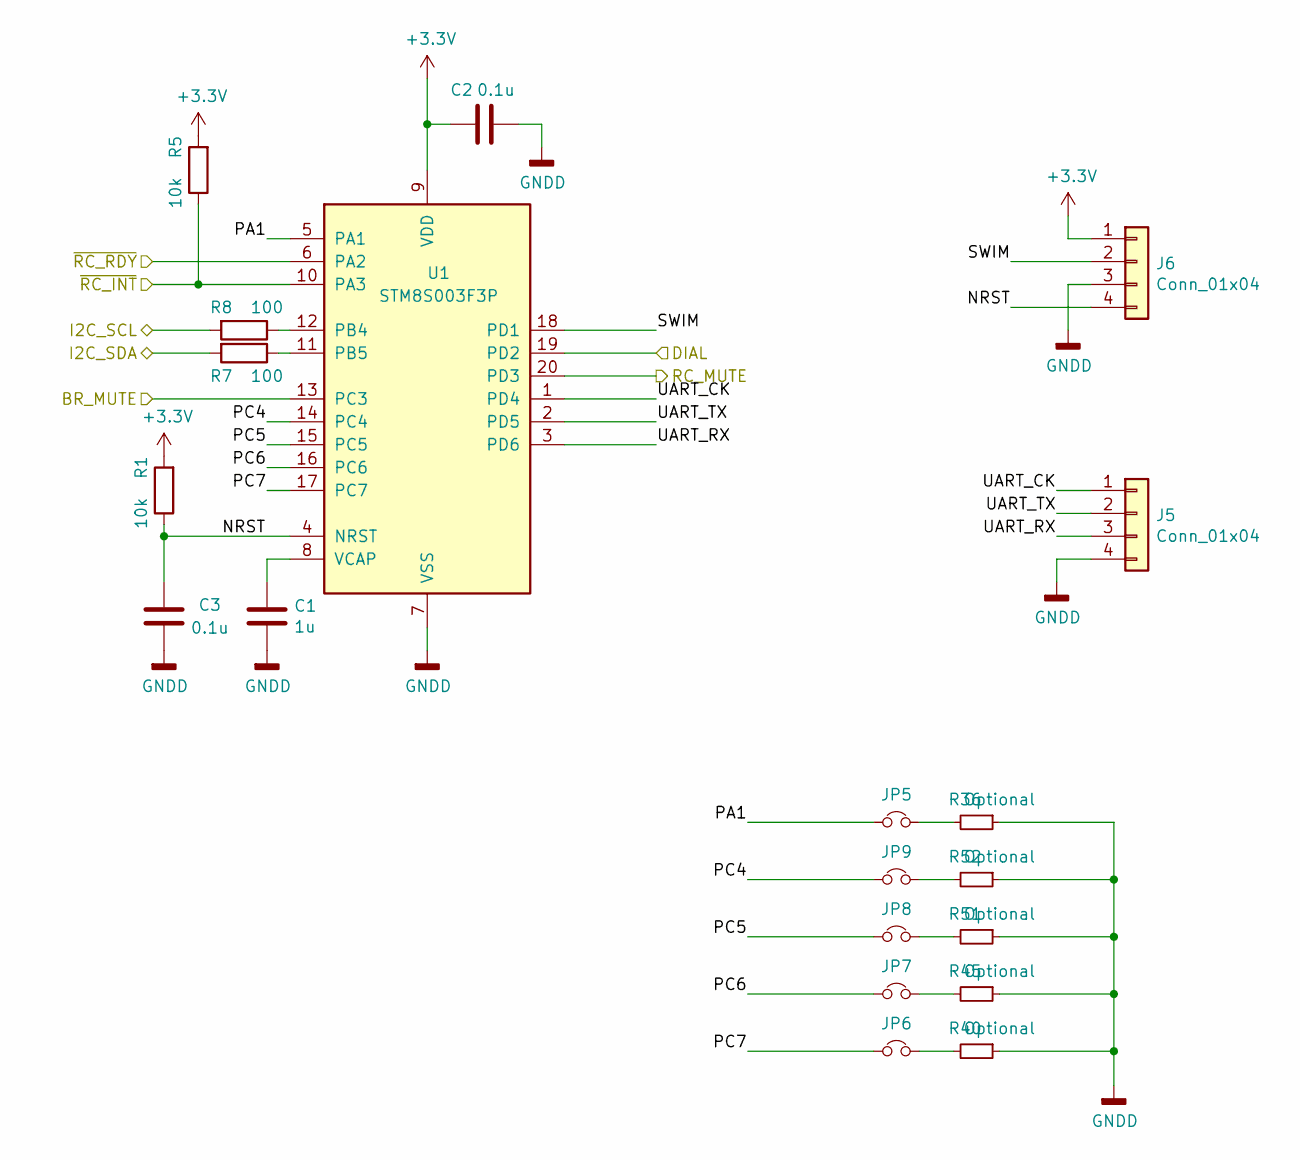
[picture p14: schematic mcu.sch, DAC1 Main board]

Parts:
C1: 1u; C_0805_2012Metric; LCSC C28323
C2, C3: 0.1u; C_0603_1608Metric; LCSC C14663
J5, J6: Conn_01x04; PinHeader_1x04_P2.54mm_Vertical
JP5, JP6, JP7, JP8, JP9: PinHeader_1x02_P2.54mm_Vertical
R1, R5: 10k; R_0402_1005Metric; LCSC C25744
R7, R8: 100; R_0402_1005Metric; LCSC C25076
R36, R40, R45, R51, R52: Optional; R_Axial_DIN0204_L3.6mm_D1.6mm_P5.08mm_Horizontal
U1: STM8S003F3P; TSSOP-20_4.4x6.5mm_P0.65mm; LCSC C52717

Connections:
/ASRC/I2C_SCL: R8.2; also elsewhere on the board
/ASRC/I2C_SDA: R7.2; also elsewhere on the board
/ASRC/MUTE: U1.20 (PD3); also elsewhere on the board
/ASRC/~INT: R5.1, U1.10 (PA3); also elsewhere on the board
/MCU/BR_MUTE: U1.13 (PC3); also elsewhere on the board
/MCU/DIAL: U1.19 (PD2); also elsewhere on the board
/MCU/NRST: C3.1, J6.4, R1.1, U1.4 (NRST)
/MCU/PA1: JP5.1, U1.5 (PA1)
/MCU/PC4: JP9.1, U1.14 (PC4)
/MCU/PC5: JP8.1, U1.15 (PC5)
/MCU/PC6: JP7.1, U1.16 (PC6)
/MCU/PC7: JP6.1, U1.17 (PC7)
/MCU/SWIM: J6.2, U1.18 (PD1)
/MCU/UART_CK: J5.1, U1.1 (PD4)
/MCU/UART_RX: J5.3, U1.3 (PD6)
/MCU/UART_TX: J5.2, U1.2 (PD5)
/MCU/~RC_RDY: U1.6 (PA2); also elsewhere on the board
GNDD: C1.2, C2.2, C3.2, J5.4, J6.3, R36.1, R40.1, R45.1, R51.1, R52.1, U1.7 (VSS); also elsewhere on the board
unnamed: C1.1, U1.8 (VCAP)
unnamed: JP5.2, R36.2
unnamed: JP6.2, R40.2
unnamed: JP7.2, R45.2
unnamed: JP8.2, R51.2
unnamed: JP9.2, R52.2
unnamed: R7.1, U1.11 (PB5)
unnamed: R8.1, U1.12 (PB4)

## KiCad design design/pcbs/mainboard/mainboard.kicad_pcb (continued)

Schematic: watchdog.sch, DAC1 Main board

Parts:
C40, C82: 22u; C_0805_2012Metric; LCSC C45783
D2, D3, D6, D7: 5V6; D_MiniMELF; LCSC C8062
D4, D5: D; D_SOD-123F; LCSC C64898
K3, K4: EC2-12NU; RELAY_EC2-5NU; DigiKey 399-11029-5-ND
Q1, Q2, Q4, Q5, Q6, Q7, Q8, Q9, Q11, Q12: SS8050; SOT-23; LCSC C2150
Q3, Q10: SS8550; SOT-23; LCSC C8542
R11, R13, R72, R74: 2.2k; R_0402_1005Metric; LCSC C25879
R12, R14, R68, R69: 5.6k; R_0402_1005Metric; LCSC C25908
R20, R73: 15k; R_0402_1005Metric; LCSC C25756
R21, R71: 10k; R_0402_1005Metric; LCSC C25744
R31, R63: 22k; R_0402_1005Metric; LCSC C25768

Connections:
+10V: D4.1 (K), K3.1, R11.1, R20.1, R31.2; also elsewhere on the board
+10V_AMP: D5.1 (K), K4.1, R63.2, R73.1, R74.1; also elsewhere on the board
-10V: C40.2, Q2.2 (E), Q4.2 (E), Q5.2 (E), R14.2; also elsewhere on the board
-10V_AMP: C82.2, Q8.2 (E), Q9.2 (E), Q11.2 (E), R68.2; also elsewhere on the board
/Headphone Amp/LOUT: K4.4; also elsewhere on the board
/Headphone Amp/ROUT: K4.9; also elsewhere on the board
/LOUT: K3.4; also elsewhere on the board
/ROUT: K3.9; also elsewhere on the board
GND_AMP: K4.3, K4.10, Q7.2 (E), Q10.1 (B), Q12.2 (E), R69.2, R71.1, R72.1; also elsewhere on the board
unnamed: C40.1, Q4.3 (C), Q5.3 (C), Q6.1 (B), R31.1
unnamed: C82.1, Q7.1 (B), Q8.3 (C), Q9.3 (C), R63.1
unnamed: D2.1 (K), R11.2, R12.1
unnamed: D2.2 (A), Q1.1 (B)
unnamed: D3.1 (K), R13.2, R14.1
unnamed: D3.2 (A), Q2.1 (B)
unnamed: D4.2 (A), K3.12, Q6.3 (C)
unnamed: D5.2 (A), K4.12, Q7.3 (C)
unnamed: D6.1 (K), R68.1, R72.2
unnamed: D6.2 (A), Q11.1 (B)
unnamed: D7.1 (K), R69.1, R74.2
unnamed: D7.2 (A), Q12.1 (B)
unnamed: Q1.3 (C), Q3.2 (E), R20.2
unnamed: Q2.3 (C), Q4.1 (B), R21.2
unnamed: Q3.3 (C), Q5.1 (B)
unnamed: Q10.2 (E), Q12.3 (C), R73.2
unnamed: Q8.1 (B), Q10.3 (C)
unnamed: Q9.1 (B), Q11.3 (C), R71.2

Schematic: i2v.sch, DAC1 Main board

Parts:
C23, C36, C50, C52, C62, C70: 10u; CP_EIA-3216-18_Kemet-A; LCSC C7171
C24, C47, C53, C69: 430p; C_0603_1608Metric; DigiKey 399-15401-1-ND
C26, C41, C46, C57, C58, C68: 0.1u; C_0603_1608Metric; LCSC C14663
C37, C38, C65, C66: 1.2n; C_0603_1608Metric; DigiKey 399-14950-1-ND
R27, R35, R43, R53: 820; R_0603_1608Metric; DigiKey RG16N820WCT-ND
R28, R30, R48, R50: 1k; R_0603_1608Metric; DigiKey RG16N1.0KWCT-ND
R33, R34, R46, R47: 270; R_0603_1608Metric; DigiKey RG16N270WCT-ND
R38, R42: 25; R_0603_1608Metric; DigiKey 764-1409-1-ND
U9, U13, U15: OPA1612AxD; SOIC-8_3.9x4.9mm_P1.27mm; DigiKey 296-39098-1-ND

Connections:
+10V: C23.1, C26.1, C36.1, C46.1, C52.1, C58.1, U9.8 (V+), U13.8 (V+), U15.8 (V+); also elsewhere on the board
-10V: C41.2, C50.2, C57.2, C62.2, C68.2, C70.2, U9.4 (V-), U13.4 (V-), U15.4 (V-); also elsewhere on the board
/DAC/I2V/IIN+L: C53.1, R43.2, U15.6 (-); also elsewhere on the board
/DAC/I2V/IIN+R: C24.1, R27.2, U9.6 (-); also elsewhere on the board
/DAC/I2V/IIN-L: C69.1, R53.2, U15.2 (-); also elsewhere on the board
/DAC/I2V/IIN-R: C47.1, R35.2, U9.2 (-); also elsewhere on the board
/LOUT: R42.1; also elsewhere on the board
/ROUT: R38.1; also elsewhere on the board
unnamed: C24.2, R27.1, R28.2, U9.7
unnamed: C37.1, R33.2, R38.2, U13.7
unnamed: C37.2, R30.1, R33.1, U13.6 (-)
unnamed: C38.1, R28.1, R34.2, U13.5 (+)
unnamed: C47.2, R30.2, R35.1, U9.1
unnamed: C53.2, R43.1, R48.2, U15.7
unnamed: C65.1, R42.2, R46.2, U13.1
unnamed: C65.2, R46.1, R50.1, U13.2 (-)
unnamed: C66.1, R47.2, R48.1, U13.3 (+)
unnamed: C69.2, R50.2, R53.1, U15.1

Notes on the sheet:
Equations defining behaviour: R1: TIA feedback R2: DA series R3: DA feedback C1: TIA feedback C3: DA feedback (1) R1*(6.2+7.8/2)*1e-3 <= 10-1 (1 V headroom w/ 10 V rail) (2) R3/R2*R1*7.8*1e-3 <= 3.472/2 (Line out level) (3) R3/R2 is minimised (Minimise noise gain) (4) 3.472 - R3/R2*R1*7.8*1e-3 is m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
TINA-TI simulations:
Phase margin 57 deg @ 37 MHz:
Group delay flat to 20 kHz:
Gain flat to 20 kHz:
Noise 700 nV RMS up to 20 kHz
In THD+N terms this noise is 0.000057% relative to a 1.228 V RMS full scale.

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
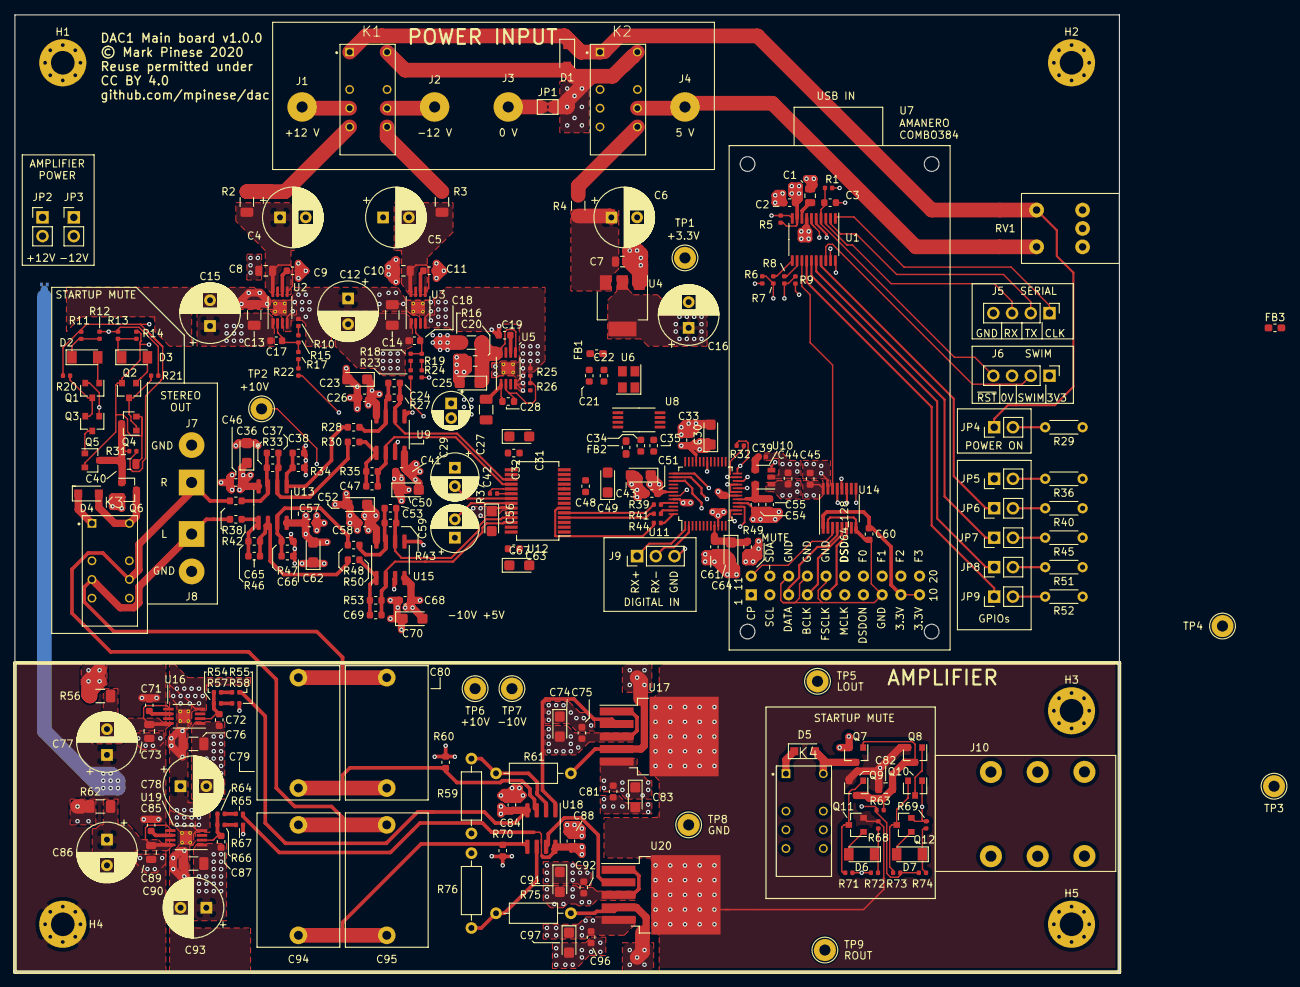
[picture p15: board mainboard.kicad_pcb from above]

Board: 4 copper layers, 150.0 x 130.0 mm, 254 parts (1 on the bottom side), 139 nets.

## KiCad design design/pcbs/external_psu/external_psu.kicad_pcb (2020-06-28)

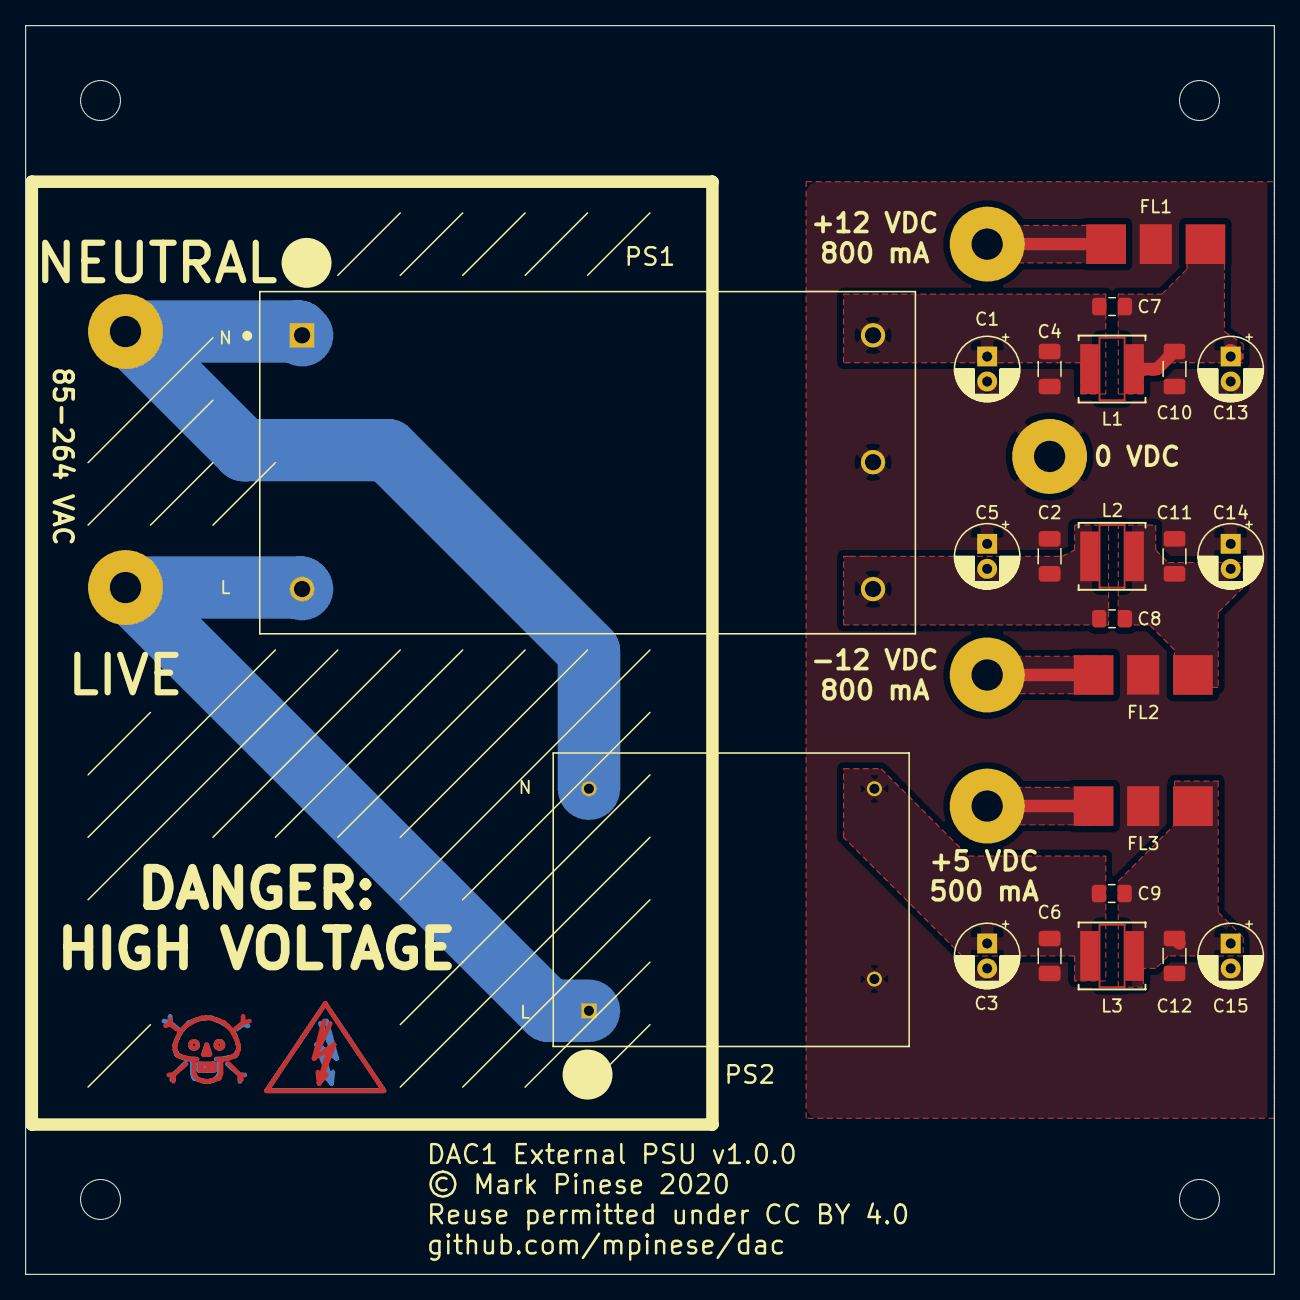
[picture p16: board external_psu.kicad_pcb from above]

Board: 2 copper layers, 100.0 x 100.0 mm, 33 parts (0 on the bottom side), 12 nets.

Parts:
C1, C2, C3, C13, C14, C15: 6.8u; CP_Radial_D5.0mm_P2.00mm
C4, C5, C6, C10, C11, C12: 2.2u; C_1206_3216Metric
C7, C8, C9: 15n; C_0805_2012Metric_Pad1.15x1.40mm_HandSolder
CONN1: L; SolderWirePad_1x01_Drill2.5mm
CONN2: N; SolderWirePad_1x01_Drill2.5mm
CONN3: +12V; SolderWirePad_1x01_Drill2.5mm
CONN4: 0V; SolderWirePad_1x01_Drill2.5mm
CONN5: -12V; SolderWirePad_1x01_Drill2.5mm
CONN6: +5V; SolderWirePad_1x01_Drill2.5mm
FL1, FL2, FL3: EMI_Filter_CLC; 4700-008MLF
H1, H2, H3, H4: MountingHole; MountingHole_3.2mm_M3
L1, L2, L3: 15u; NRS5020T150MMGJ
PS1: RAC20-12DK; CONV_RAC20-12DK
PS2: RAC03-05SK; CONV_RAC03-05SK

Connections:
/LIVE: CONN1.1, PS1.2, PS2.1
/NEUTRAL: CONN2.1, PS1.1, PS2.4
GND: C1.2, C2.1, C3.2, C4.2, C5.2, C6.2, C10.2, C11.2, C12.2, C13.2, C14.1, C15.2, CONN4.1, FL1.2, FL2.2, FL3.2, PS1.4, PS2.2
unnamed: C1.1, C4.1, C7.1, L1.1, PS1.5
unnamed: C2.2, C5.1, C8.1, L2.1, PS1.3
unnamed: C3.1, C6.1, C9.1, L3.1, PS2.3
unnamed: C7.2, C10.1, C13.1, FL1.1, L1.2
unnamed: C8.2, C11.1, C14.2, FL2.1, L2.2
unnamed: C9.2, C12.1, C15.1, FL3.1, L3.2
unnamed: CONN3.1, FL1.3
unnamed: CONN5.1, FL2.3
unnamed: CONN6.1, FL3.3

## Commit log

2020-06-25 Initial commit.
    [CUI_DEVICES_PD-40.step, RAC20-15DK--3DModel-STEP-1.STEP, asrc.sch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]
2020-06-27 Added jitter simulation that supports the use of a 5 ps RMS jitter oscillator.
2020-06-27 Completed layout of main board, cleaned up some libraries.
    [clock.sch, mainboard.kicad_pcb, mcu.sch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]
2020-06-27 Fixed mounting hole alignment
    [mainboard.kicad_pcb]
2020-06-27 Tweaked silkscreen to better identify optional modules.
    [mainboard.kicad_pcb]
2020-06-27 Renumbered footprints to follow board position.
    [asrc.sch, clock.sch, dac.sch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]
2020-06-27 Fixed PCB 3D models.
    [mainboard.kicad_pcb]
2020-06-27 Silkscreen tweaks
    [mainboard.kicad_pcb]
2020-06-27 Updated PCB sheet info. Clarified licence in readme.
    [clock.sch, external_psu.kicad_pcb, external_psu.sch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]
2020-06-27 Removed outdated files.
    [i2vl.sch, i2vr.sch, simulations.sch]
2020-06-27 Removed tracking of Kicad -bak files.
2020-06-28 Fixed title blocks. Added fab outputs.
    [asrc.sch, clock.sch, dac.sch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]
2020-09-04 Misc updates
    [asrc.sch, clock.sch, dac.sch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]

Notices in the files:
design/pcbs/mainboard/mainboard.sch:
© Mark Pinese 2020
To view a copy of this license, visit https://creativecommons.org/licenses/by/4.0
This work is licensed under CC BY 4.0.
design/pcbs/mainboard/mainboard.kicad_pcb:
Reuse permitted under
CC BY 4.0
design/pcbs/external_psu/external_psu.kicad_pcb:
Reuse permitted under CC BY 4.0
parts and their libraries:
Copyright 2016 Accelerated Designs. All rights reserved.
